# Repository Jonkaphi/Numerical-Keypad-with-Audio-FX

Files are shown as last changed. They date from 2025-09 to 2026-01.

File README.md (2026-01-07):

# Mechanical Numerical Keypad with local Audio FX
The desire to make this little keypad came from idea to reuse a some of the parts from a broken keyboard someone gave me.

The extra little feature of having audio fx being played locally on the keyboard with each button press, was from one of the commenters on reddit related to a post. The sound files will be read from the placed SD card. Currently the audio that can be played is from 8 to 16 kHz kHz sample rate with 16 bit signed PCM.

The lower level sd card interface for the file system used in the project was made by Khaled Magdy in their post on DeepBlueMbedded

### Top View
kuk35721-1920

### Bottom View



## Issues as of 08/2025
* Current USB port part is not vertically offset, which collides with the PCB, read "Connectors" page in the schematic.
* Encoder for PC system audio still glitches at times, but its significantly better compared to previous build versions
* Audio streaming and polling of the key inputs is done on a single thread, resulting in less than satisfactory responsiveness

## Future work
* Move to a MCU series that include SDIO for the SD card, has more flash to as to implement some sort of RTOS, and or has a second core to handle the audio streaming.
* General rework of the PCB, redesign of the audio front-end to have better amplification of the DAC data stream.

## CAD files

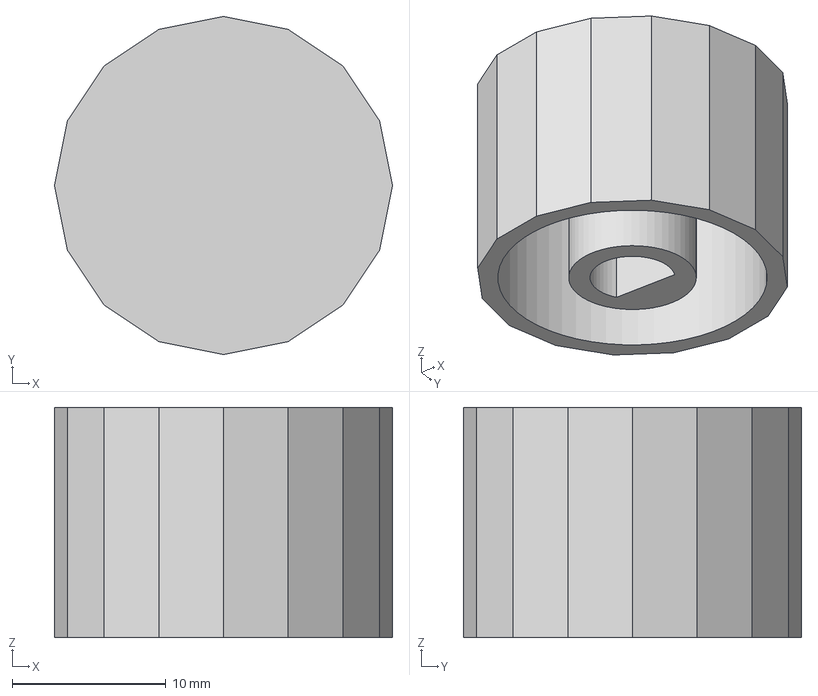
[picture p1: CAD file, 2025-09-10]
Hardware/keyboard_case_wip/volume knob v17.step
22.0 x 22.0 x 15.0 mm

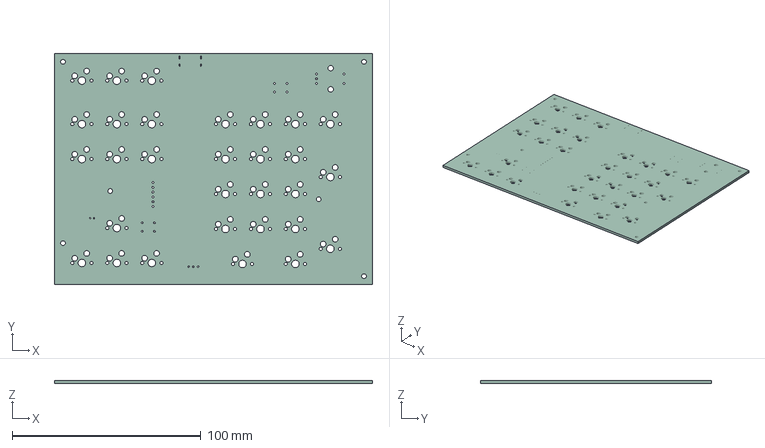
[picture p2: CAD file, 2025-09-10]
Hardware/kicad project/Body1.3mf
168.3 x 122.5 x 1.60 mm

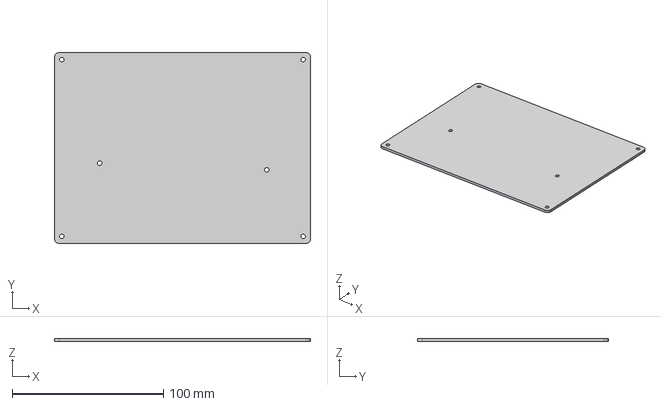
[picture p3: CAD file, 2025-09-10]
Hardware/keyboard_case_wip/bottom_plate v24.step
169.0 x 126.0 x 2.00 mm

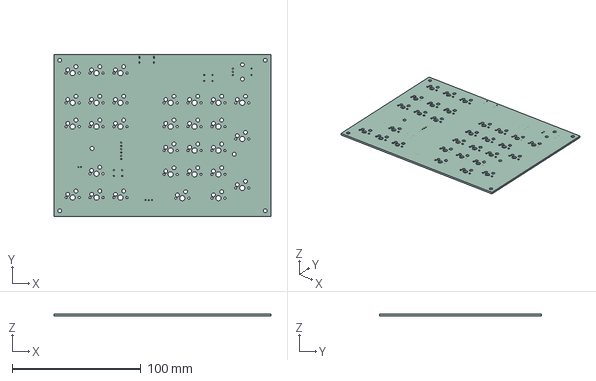
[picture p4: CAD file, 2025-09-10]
Hardware/kicad project/Keyboard_stm32.step
168.3 x 125.7 x 1.60 mm

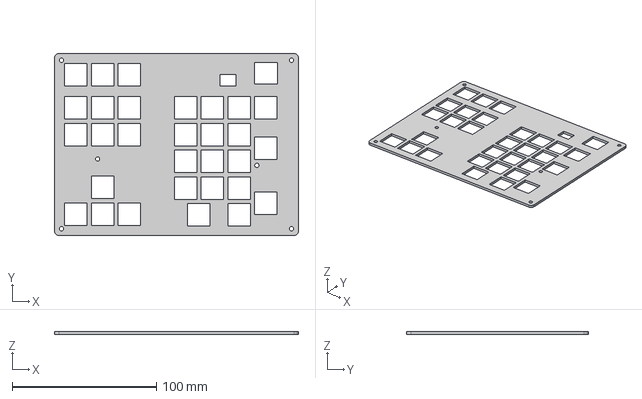
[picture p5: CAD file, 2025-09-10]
Hardware/keyboard_case_wip/top_plate v22.step
169.0 x 126.0 x 2.00 mm

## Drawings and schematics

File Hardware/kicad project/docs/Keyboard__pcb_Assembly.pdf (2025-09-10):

NRST | Power
SWDIO C²⁹ | FB3 R7

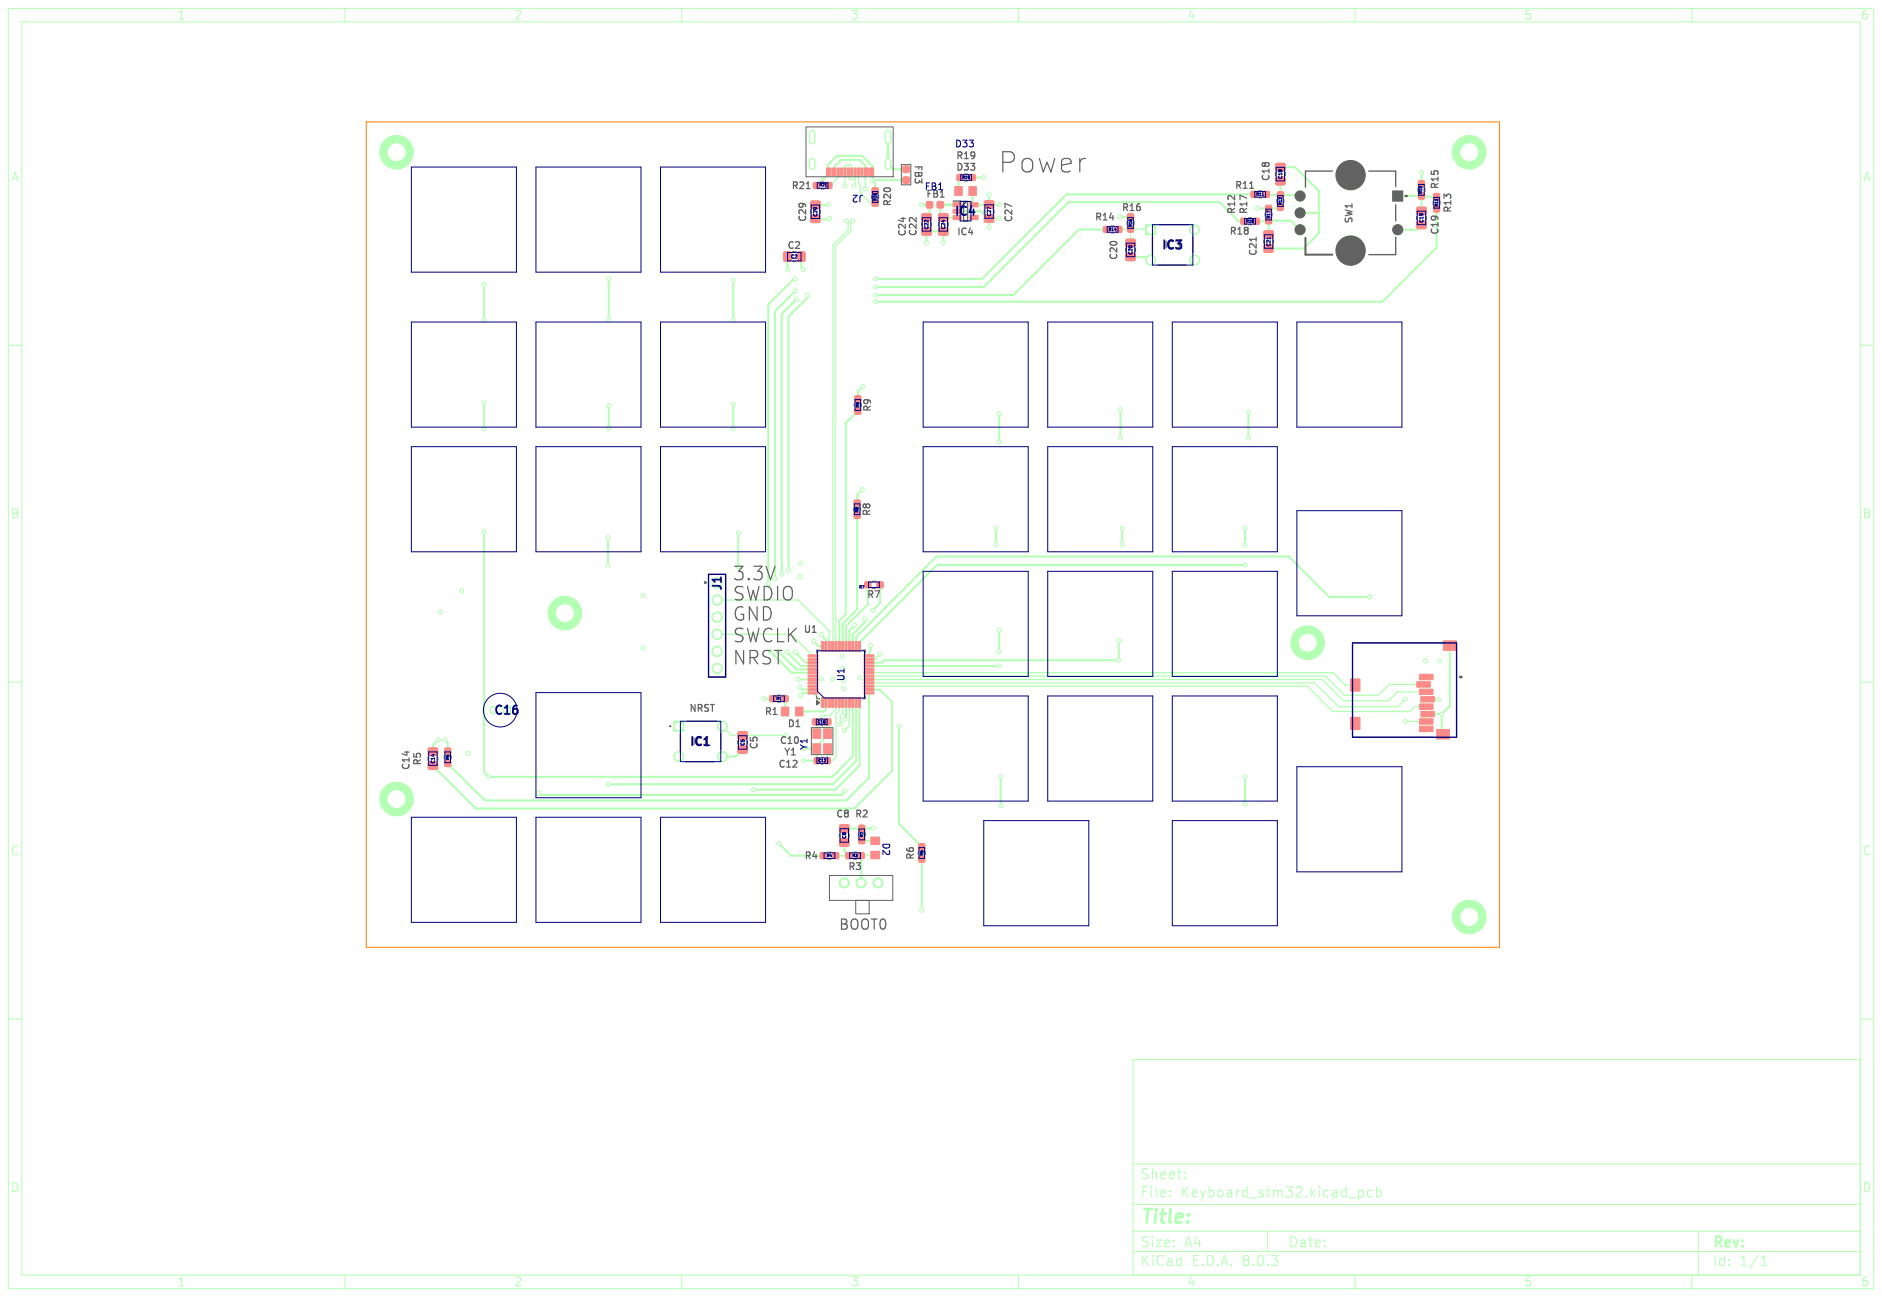
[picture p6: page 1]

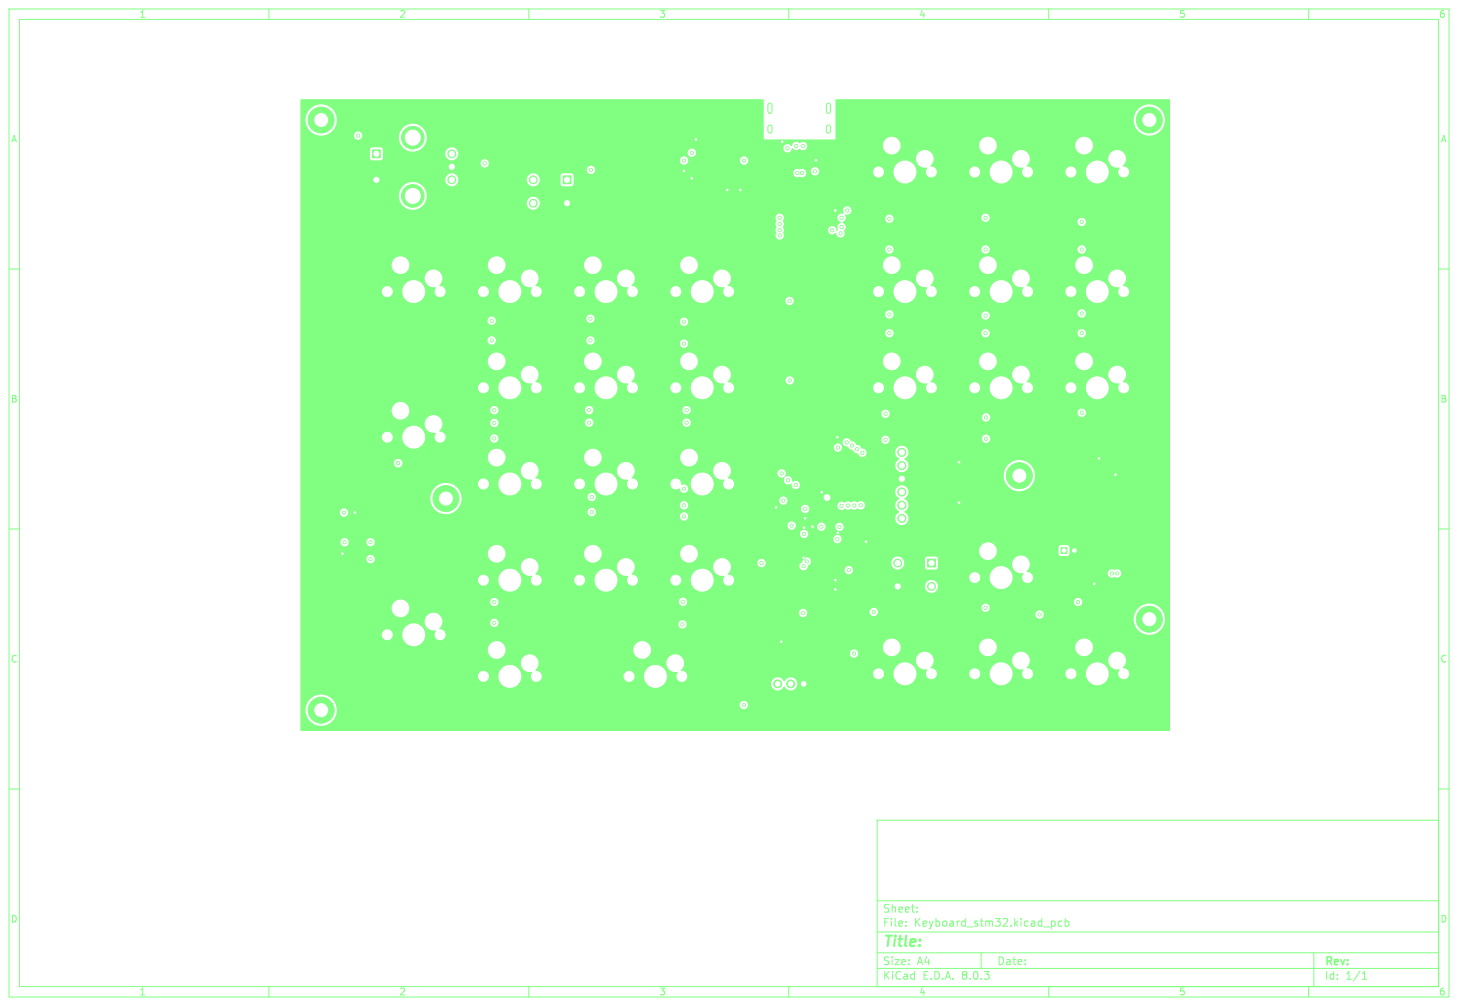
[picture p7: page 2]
D Date: KiCad; E.D.A. 8.0.3 Size: A4; Rev:

Id: 1/1 Title: File: Keyboard_stm32.kicad_pcb Sheet:

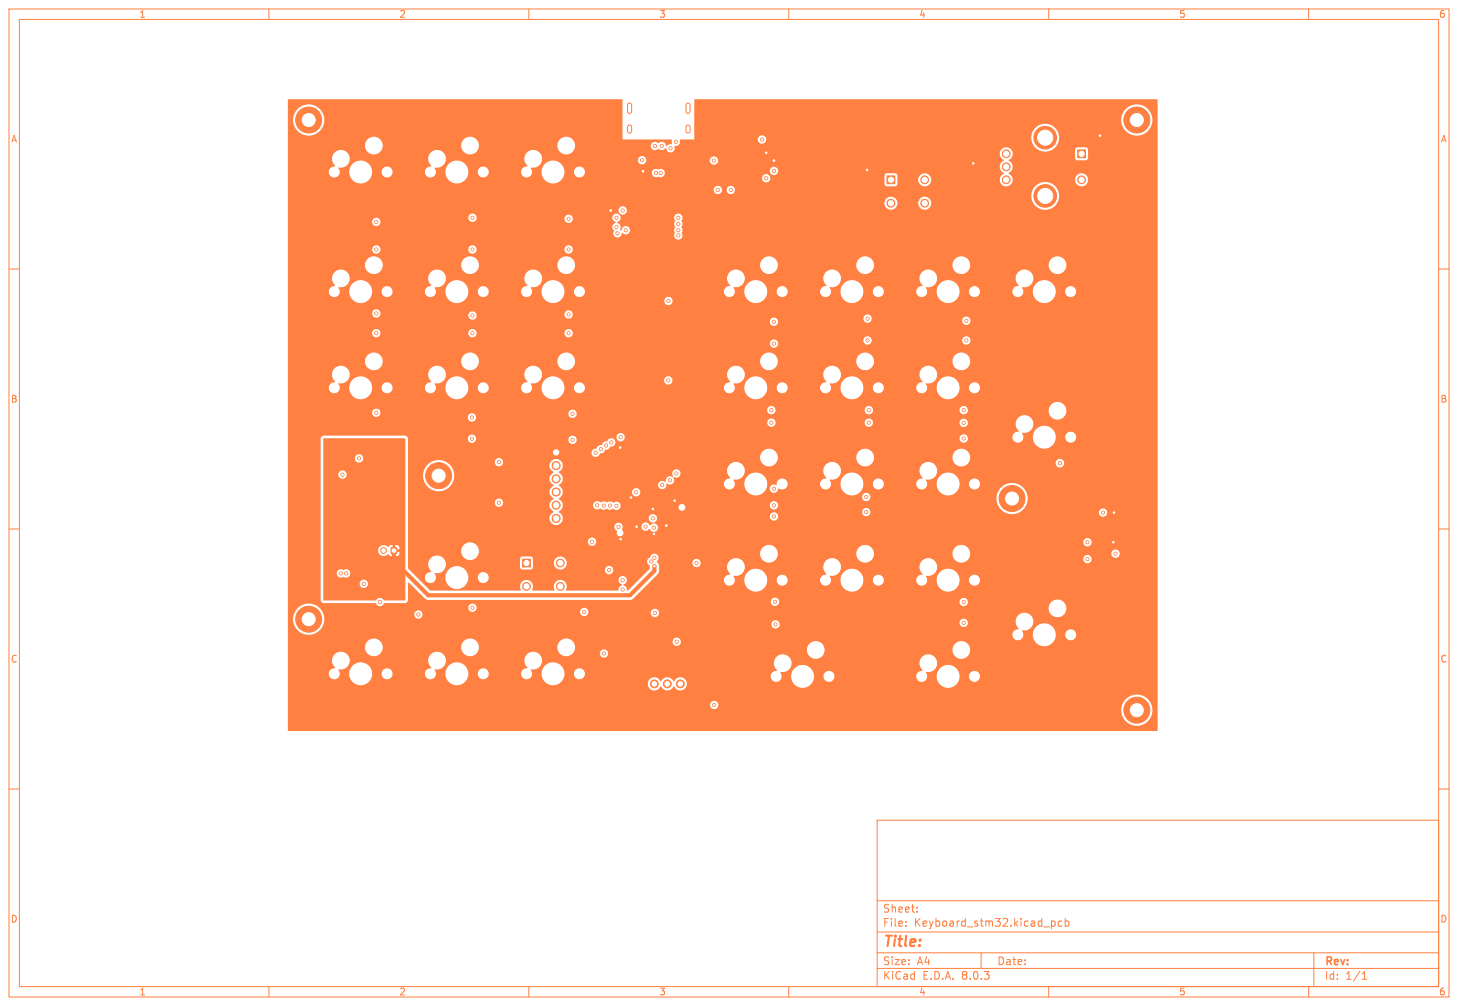
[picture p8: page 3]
D Date: KiCad; E.D.A. 8.0.3 Size: A4; Rev:

Id: 1/1 Title: File: Keyboard_stm32.kicad_pcb Sheet:

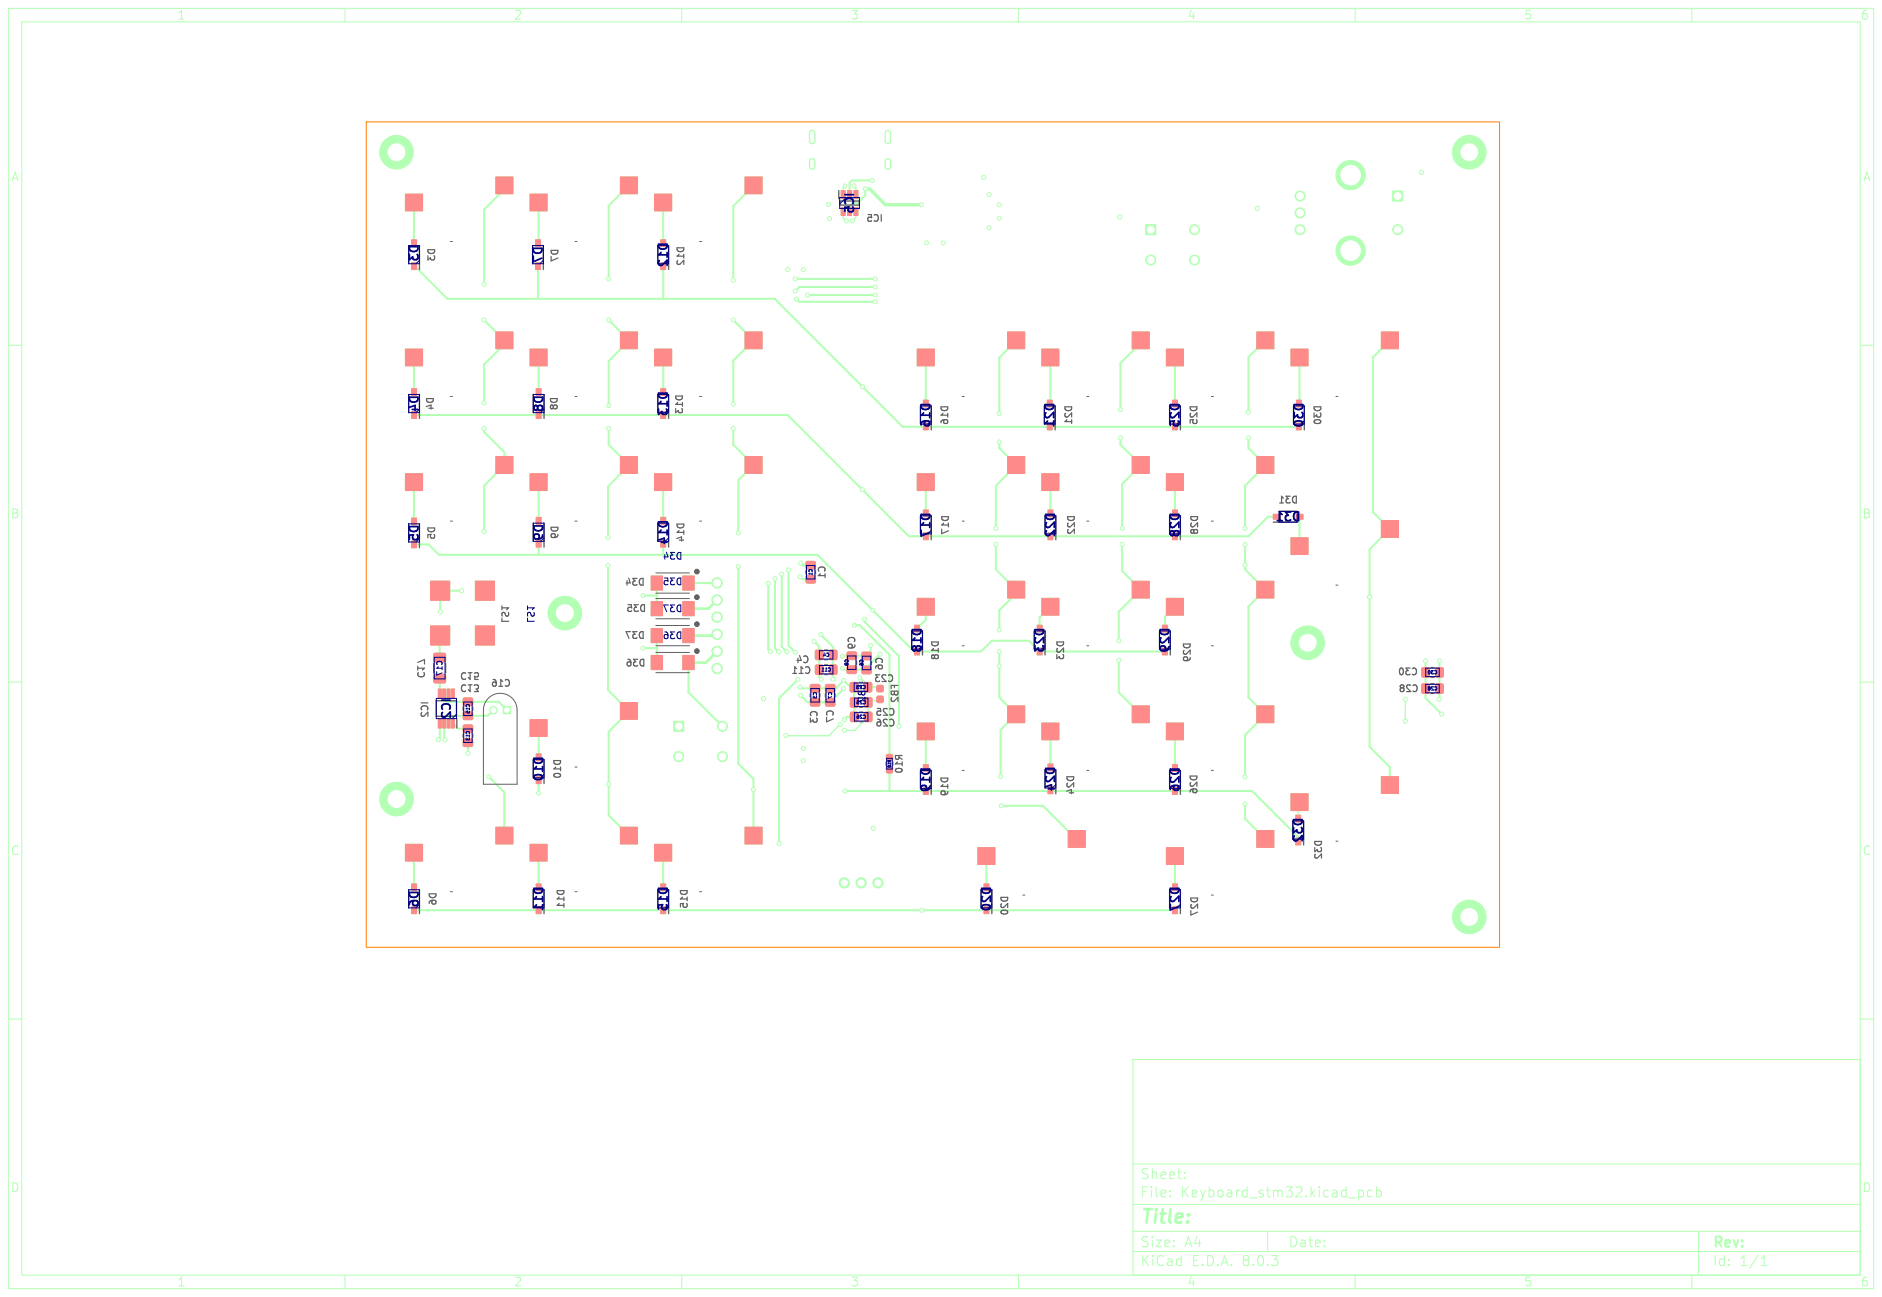
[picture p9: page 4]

Id: 1/1 Title: File: Keyboard_stm32.kicad_pcb Sheet:

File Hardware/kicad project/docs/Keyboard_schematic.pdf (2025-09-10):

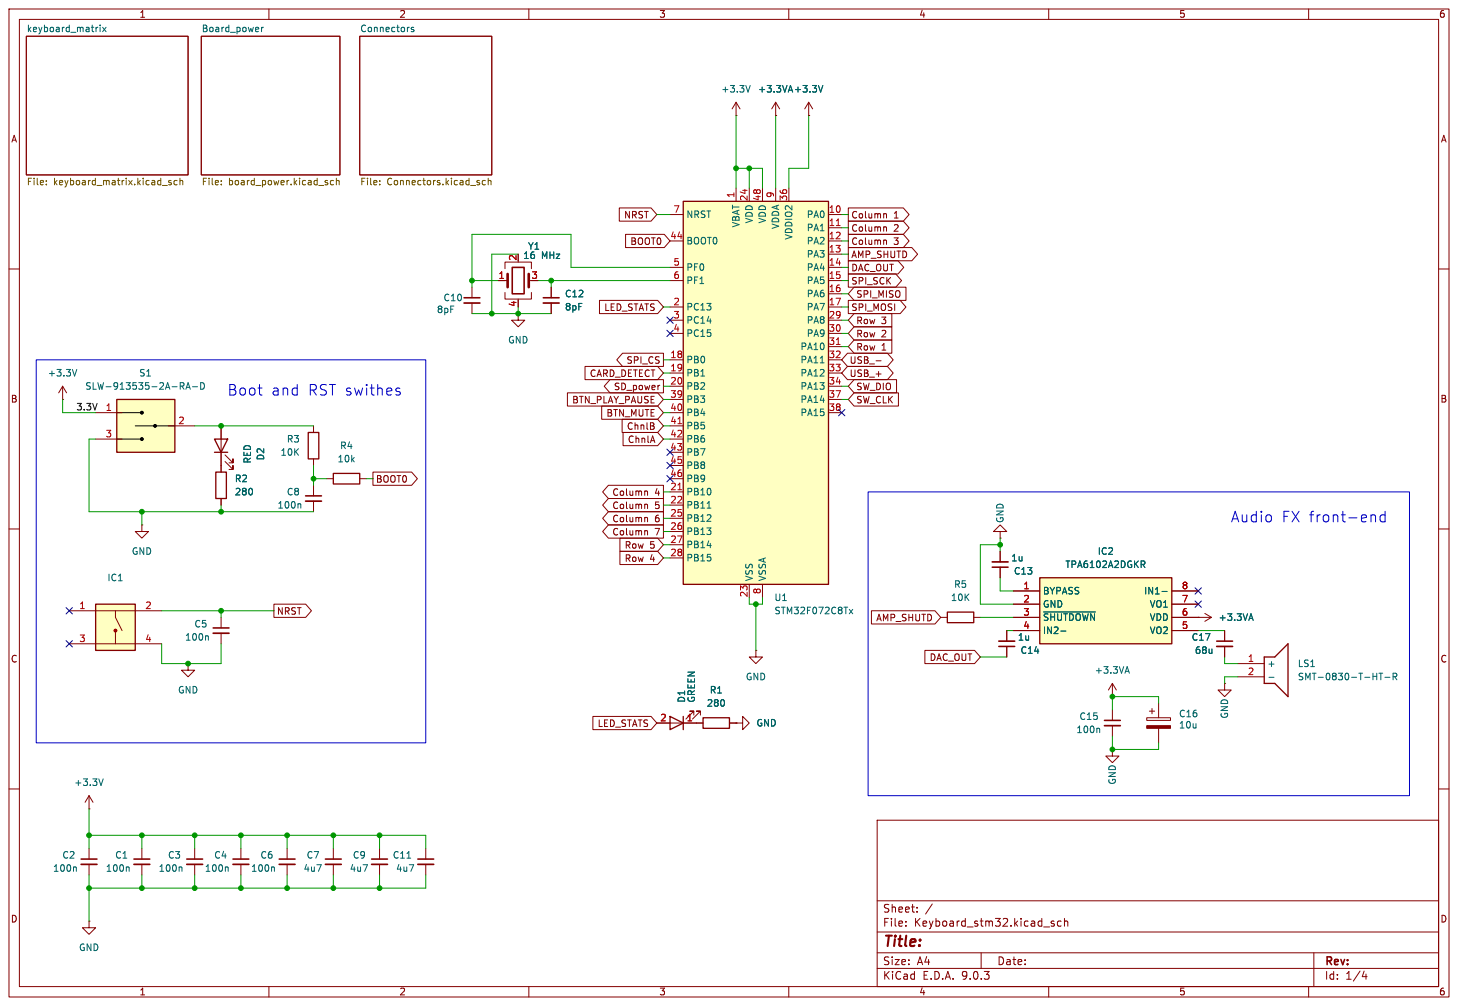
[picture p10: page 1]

1 VDD 24 VSS 23 VDD 48 VSSA

Audio FX front-end

Id: 1/4 Title: File: Keyboard_stm32.kicad_sch Sheet: /

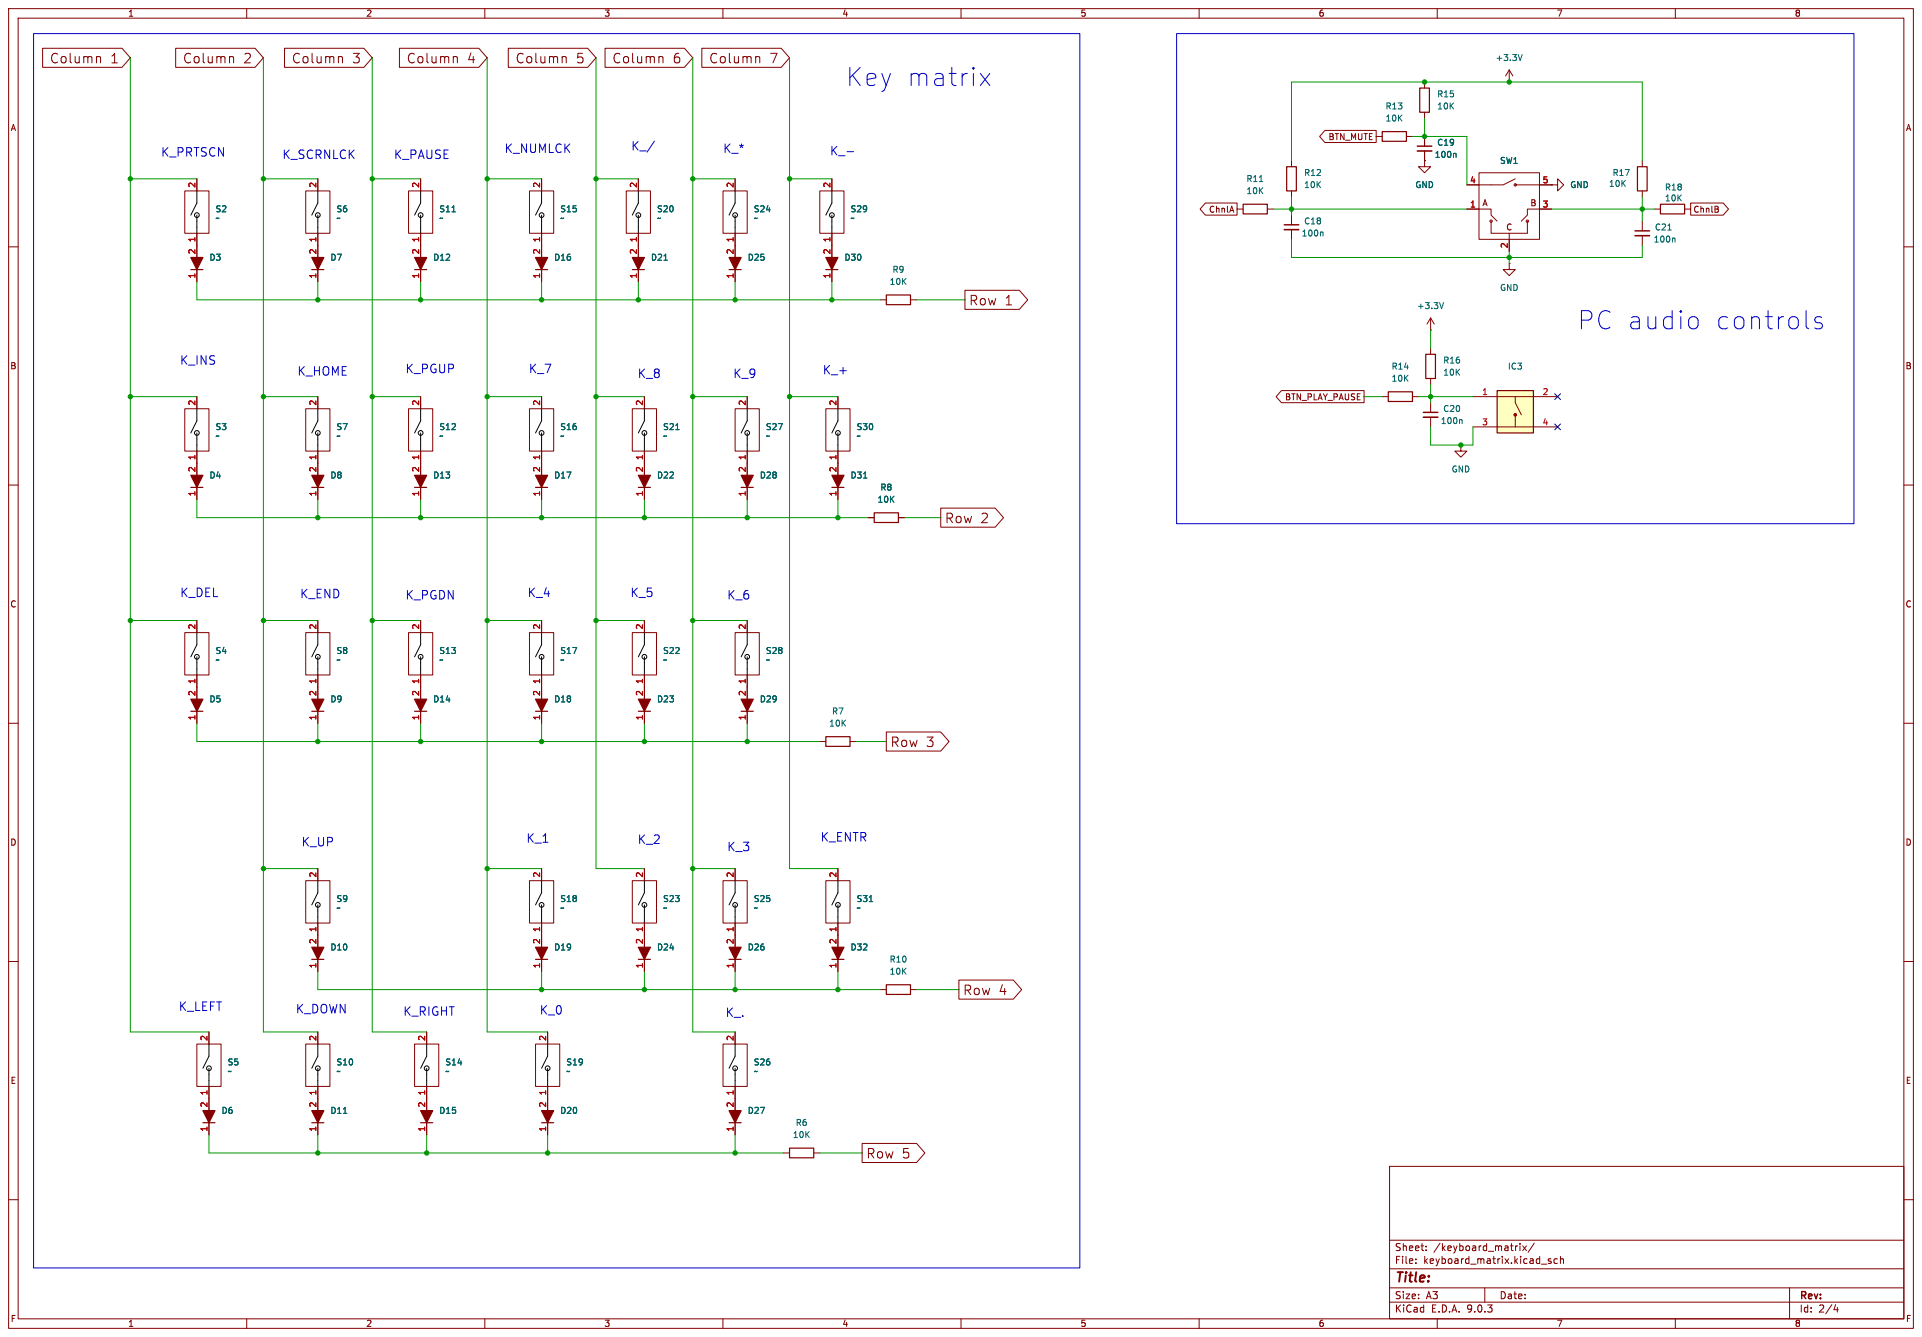
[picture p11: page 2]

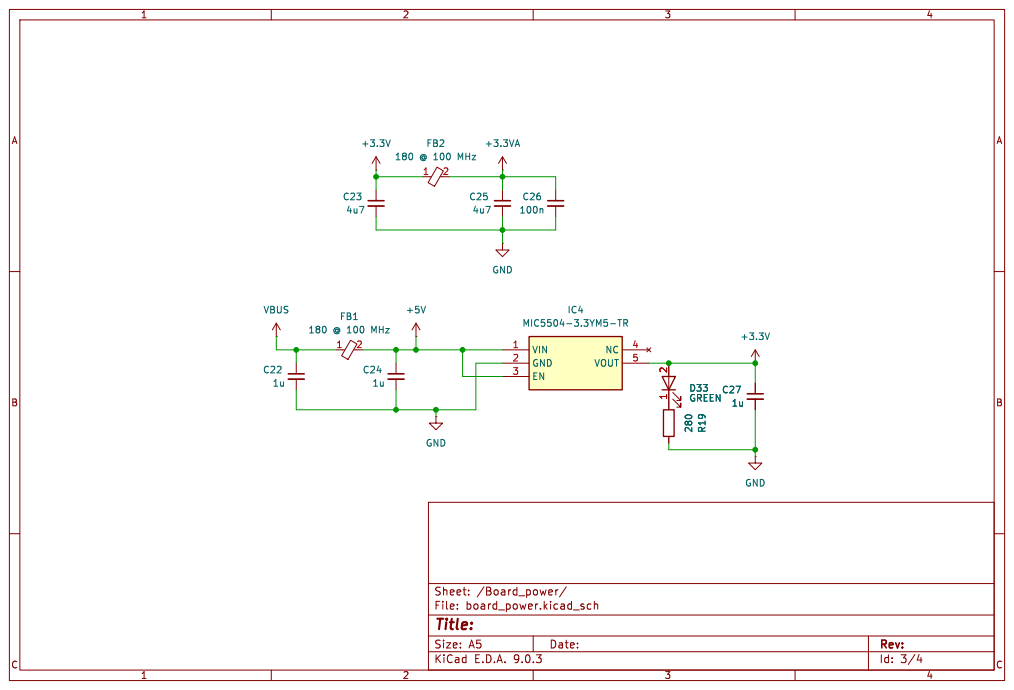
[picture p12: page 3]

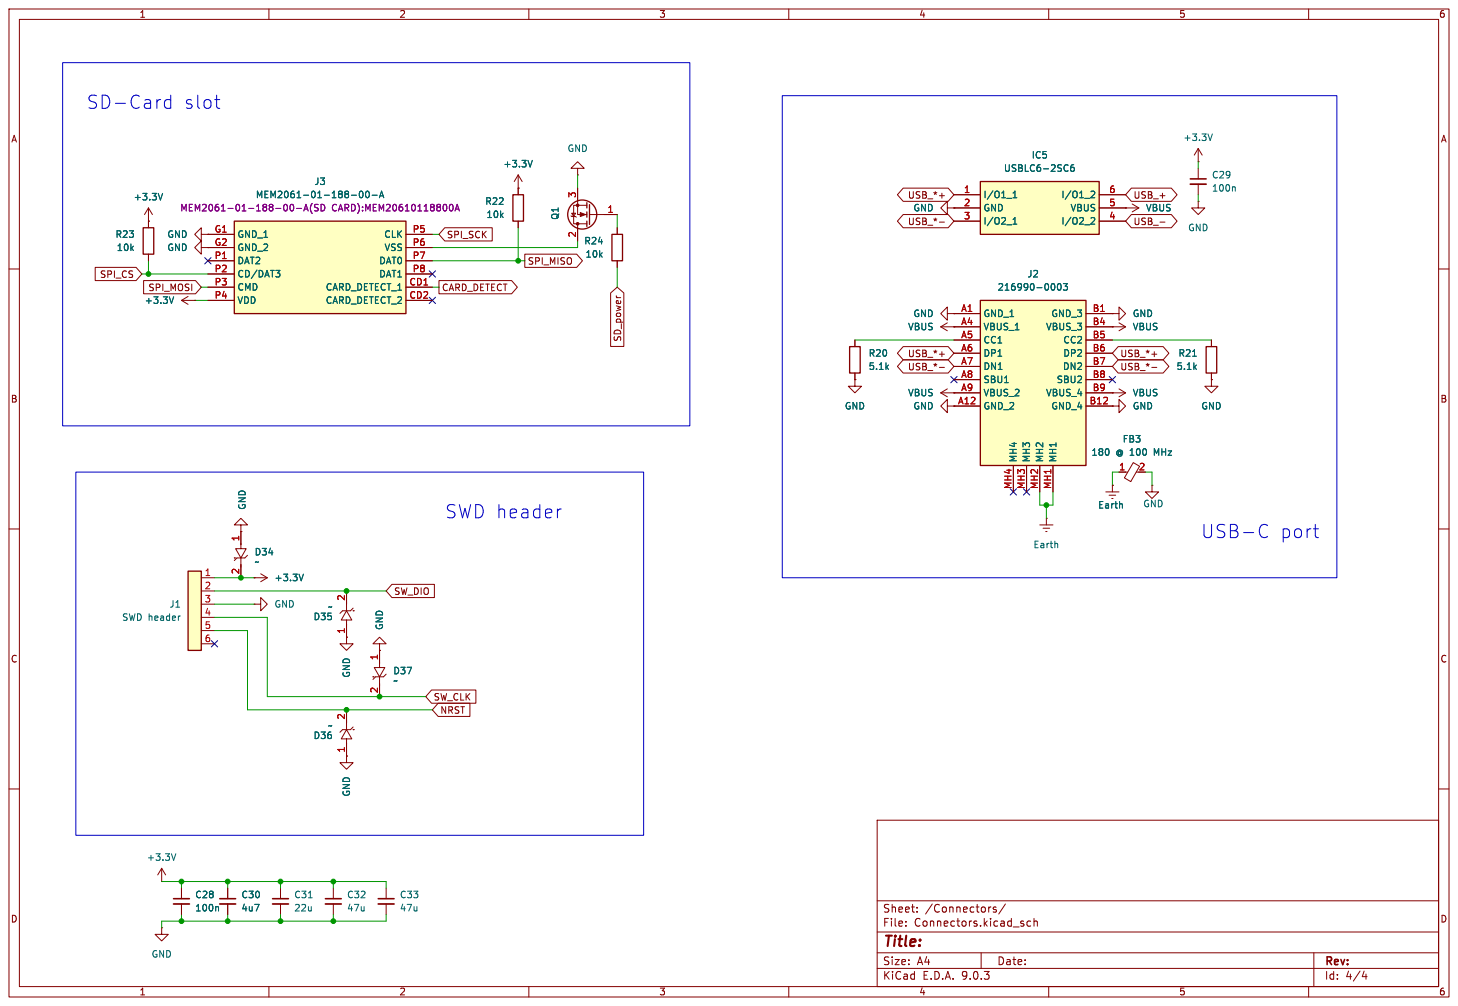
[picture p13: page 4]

Id: 4/4 Title: File: Connectors.kicad_sch Sheet: /Connectors/

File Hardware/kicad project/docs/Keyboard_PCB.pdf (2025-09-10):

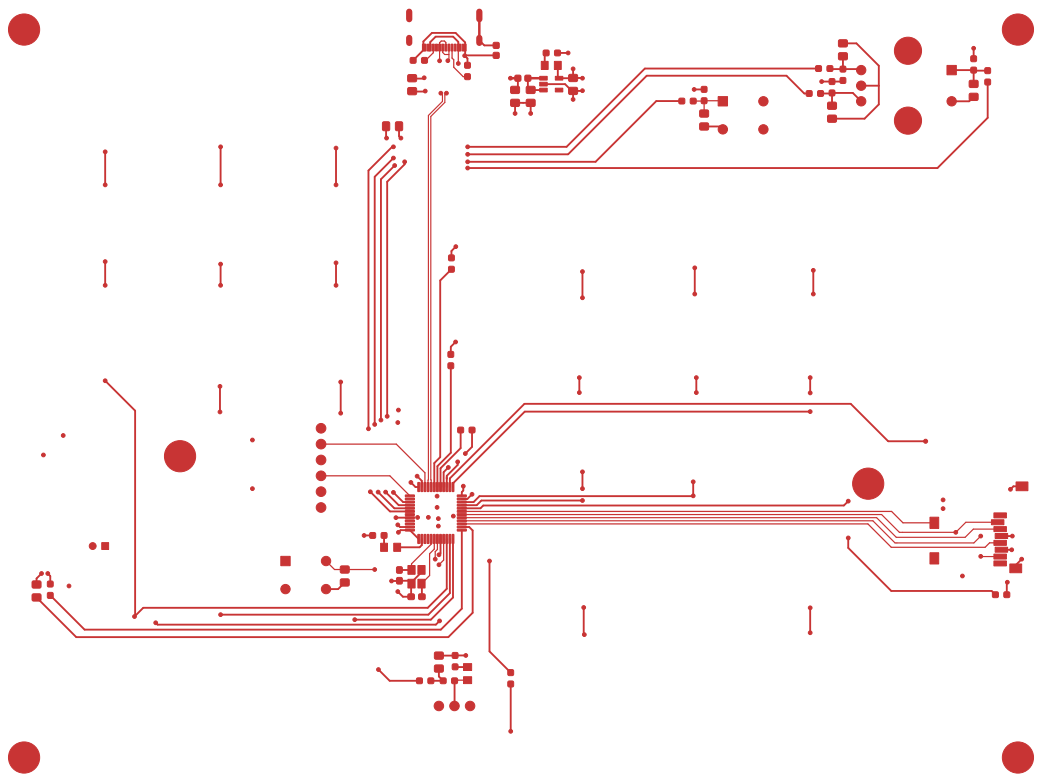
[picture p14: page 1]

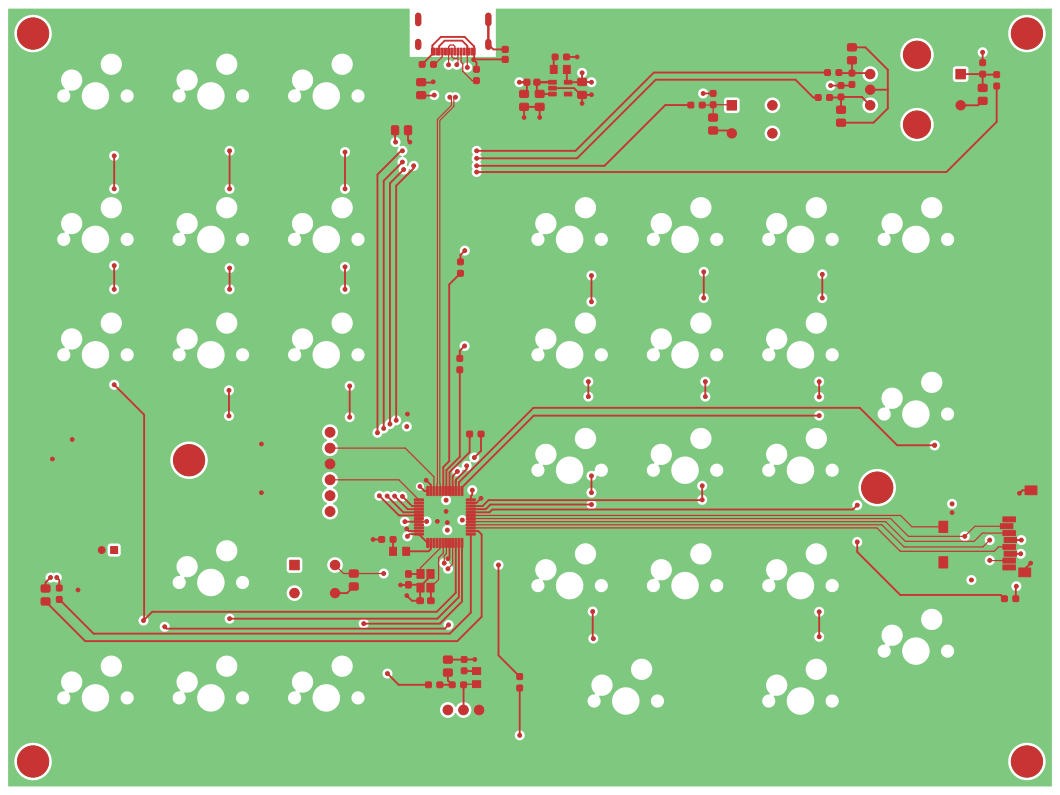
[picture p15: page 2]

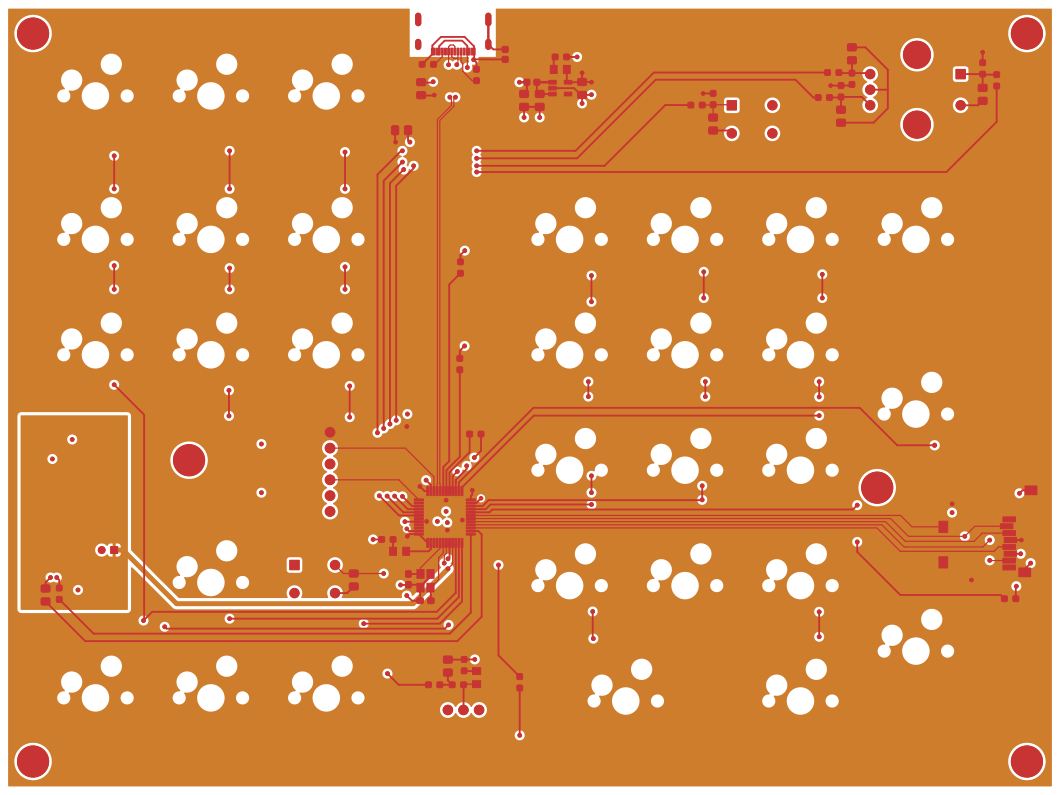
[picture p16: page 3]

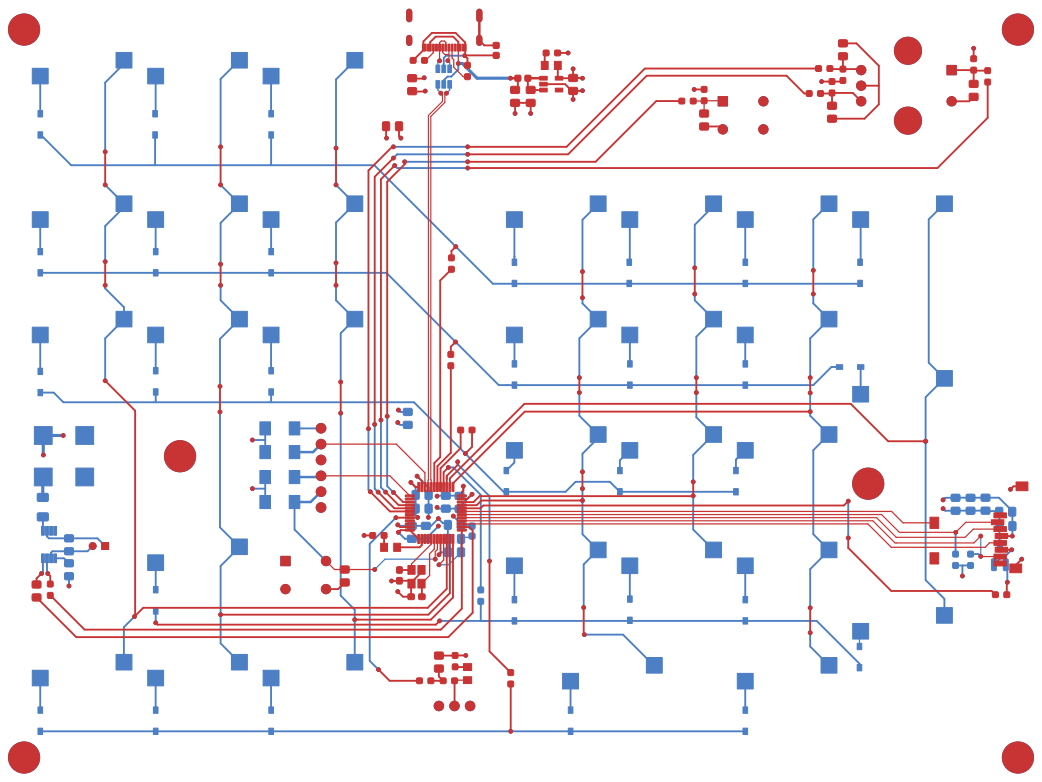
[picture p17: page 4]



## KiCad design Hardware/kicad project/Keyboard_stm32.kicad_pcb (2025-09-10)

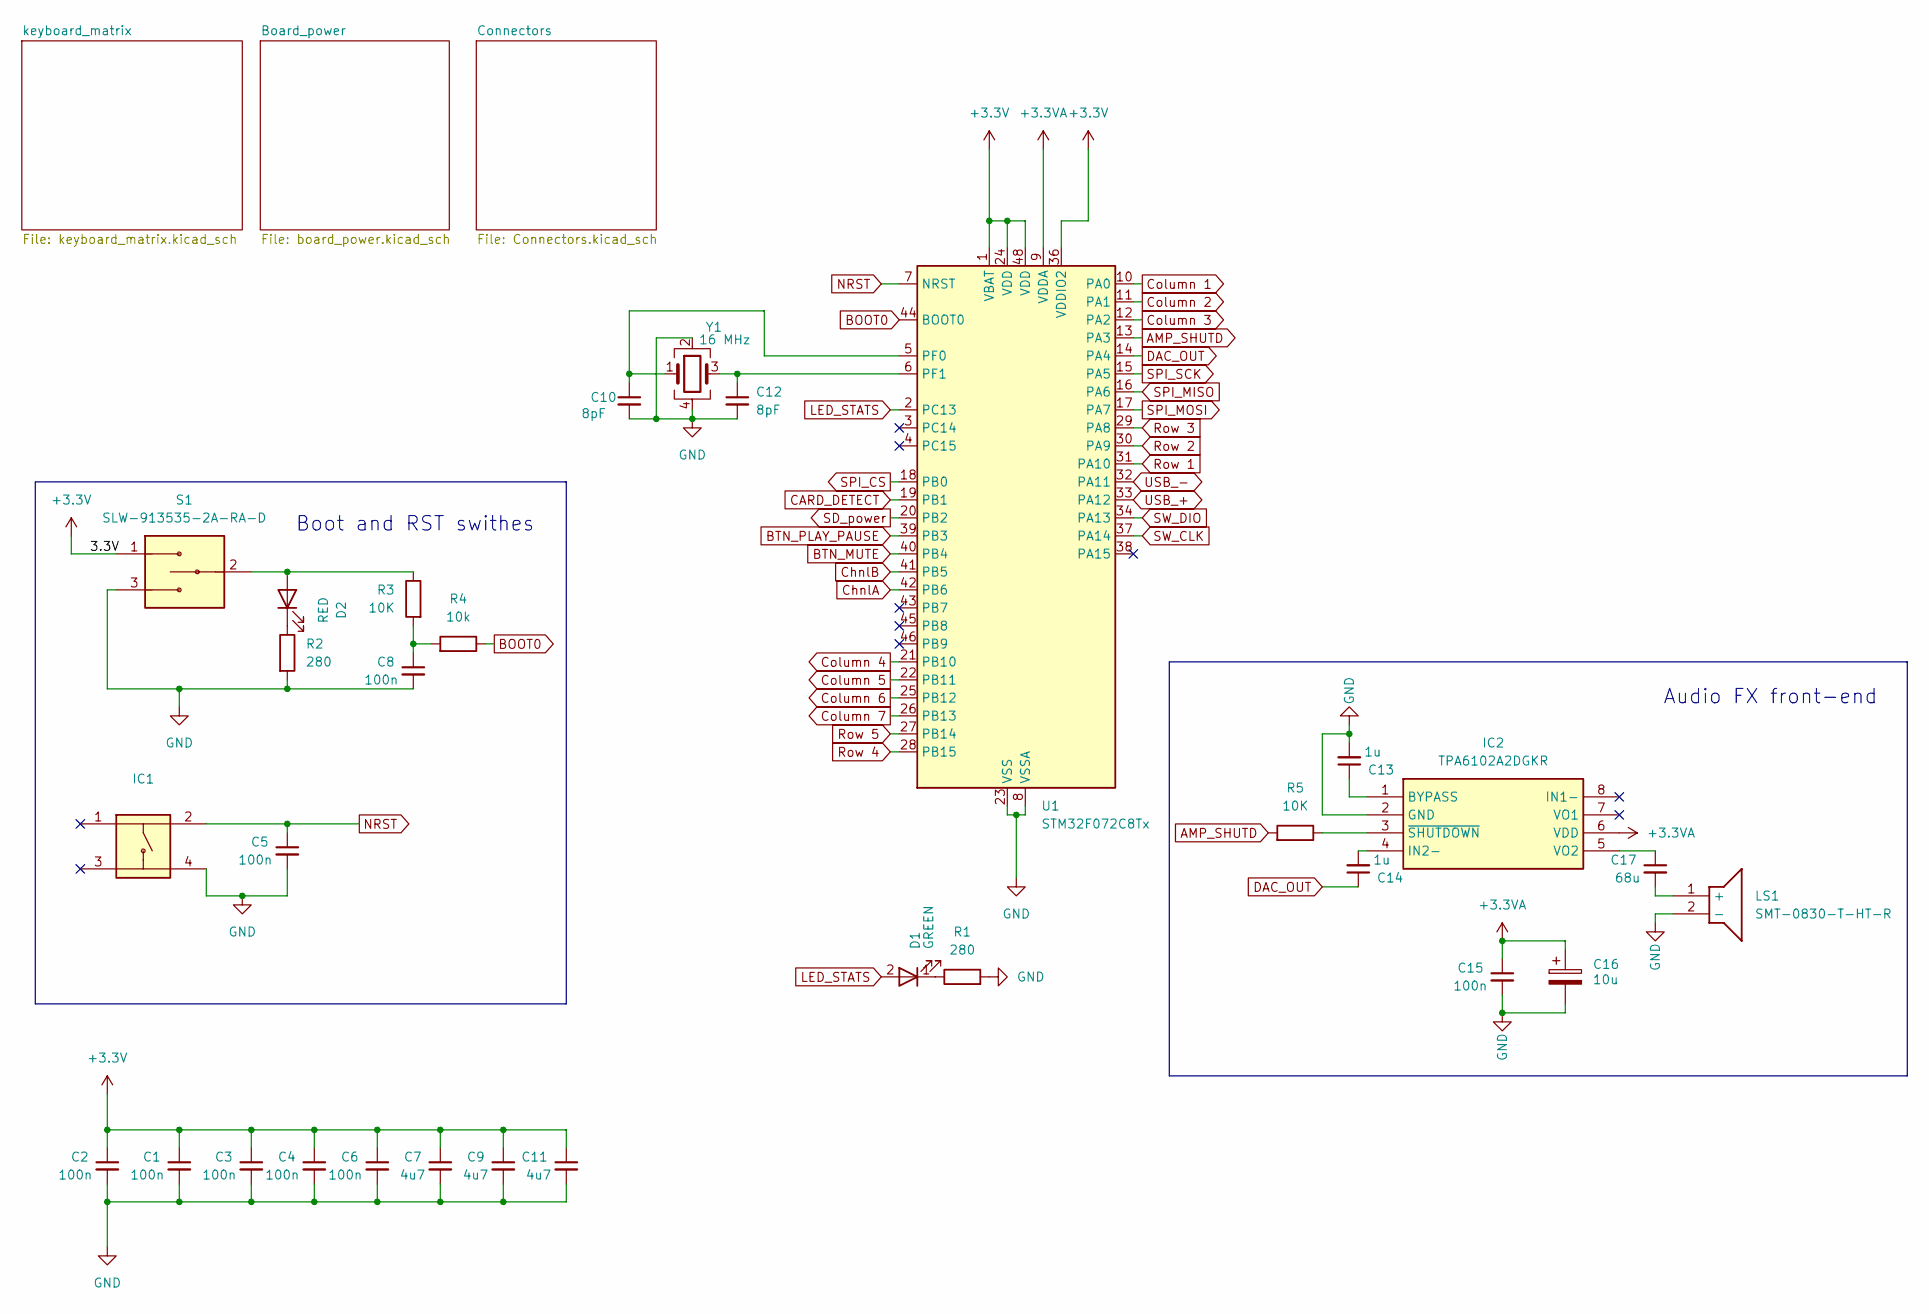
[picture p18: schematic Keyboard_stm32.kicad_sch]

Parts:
C1, C2, C3, C4, C5, C6, C8, C15: 100n; C_0805_2012Metric_Pad1.18x1.45mm_HandSolder
C7, C9, C11: 4u7; C_0805_2012Metric_Pad1.18x1.45mm_HandSolder
C10, C12: 8pF; C_0603_1608Metric_Pad1.08x0.95mm_HandSolder
C13, C14: 1u; C_0805_2012Metric_Pad1.18x1.45mm_HandSolder
C16: 10u; CAPPRD200W52D500H1250
C17: 68u; C_1206_3216Metric_Pad1.33x1.80mm_HandSolder
D1: GREEN; 150080VS75000
D2: RED; 150080VS75000
IC1: TS02-66-80-BK-160-LCR-D; TS026680BK160LCRD; Manufacturer_Part_Number TS02-66-80-BK-160-LCR-D; Mouser Part Number 179-TS026680BK160LCR
IC2: TPA6102A2DGKR; SOP65P490X110-8N; Manufacturer_Part_Number TPA6102A2DGKR; Mouser Part Number 595-TPA6102A2DGKR
LS1: SMT-0830-T-HT-R; Manufacturer_Part_Number TE122001-6; Mouser Part Number 497-TE122001-6
R1, R2: 280; R_0603_1608Metric_Pad0.98x0.95mm_HandSolder
R3, R5: 10K; R_0603_1608Metric_Pad0.98x0.95mm_HandSolder
R4: 10k; R_0603_1608Metric_Pad0.98x0.95mm_HandSolder
S1: SLW-913535-2A-RA-D; Manufacturer_Part_Number EG1218; Mouser Part Number 612-EG1218
U1: STM32F072C8Tx; LQFP-48_7x7mm_P0.5mm
Y1: 16 MHz; TSX-3225_16.0000MF09Z-AC3

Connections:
AMP_SHUTD: R5.2, U1.13 (PA3)
BOOT0: R4.1, U1.44 (BOOT0)
BTN_MUTE: U1.40 (PB4); also elsewhere on the board
BTN_PLAY_PAUSE: U1.39 (PB3); also elsewhere on the board
CARD_DETECT: U1.19 (PB1); also elsewhere on the board
ChnlA: U1.42 (PB6); also elsewhere on the board
ChnlB: U1.41 (PB5); also elsewhere on the board
Column 1: U1.10 (PA0); also elsewhere on the board
Column 2: U1.11 (PA1); also elsewhere on the board
Column 3: U1.12 (PA2); also elsewhere on the board
Column 4: U1.21 (PB10); also elsewhere on the board
Column 5: U1.22 (PB11); also elsewhere on the board
Column 6: U1.25 (PB12); also elsewhere on the board
Column 7: U1.26 (PB13); also elsewhere on the board
DAC_OUT: C14.1, U1.14 (PA4)
LED_STATS: D1.2, U1.2 (PC13)
NRST: C5.1, IC1.2, U1.7 (NRST); also elsewhere on the board
unnamed: C8.1, R3.2, R4.2
unnamed: D1.1, R1.1
unnamed: D2.2 (A), R3.1, S1.2
unnamed: D2.1 (K), R2.1
unnamed: C13.1, IC2.1 (BYPASS)
unnamed: C14.2, IC2.4 (IN2-)
unnamed: C17.1, IC2.5 (VO2)
unnamed: IC2.3 (~SHUTDOWN), R5.1
unnamed: C17.2, LS1.1 (+)
unnamed: C10.1, U1.5 (PF0), Y1.1
unnamed: C12.1, U1.6 (PF1), Y1.3
Row 1: U1.31 (PA10); also elsewhere on the board
Row 2: U1.30 (PA9); also elsewhere on the board
Row 3: U1.29 (PA8); also elsewhere on the board
Row 4: U1.28 (PB15); also elsewhere on the board
Row 5: U1.27 (PB14); also elsewhere on the board
SD_power: U1.20 (PB2); also elsewhere on the board
SPI_CS: U1.18 (PB0); also elsewhere on the board
SPI_MISO: U1.16 (PA6); also elsewhere on the board
SPI_MOSI: U1.17 (PA7); also elsewhere on the board
SPI_SCK: U1.15 (PA5); also elsewhere on the board
SW_CLK: U1.37 (PA14); also elsewhere on the board
SW_DIO: U1.34 (PA13); also elsewhere on the board
USB_+: U1.33 (PA12); also elsewhere on the board
USB_-: U1.32 (PA11); also elsewhere on the board

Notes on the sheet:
Boot and RST swithes
Audio FX front-end

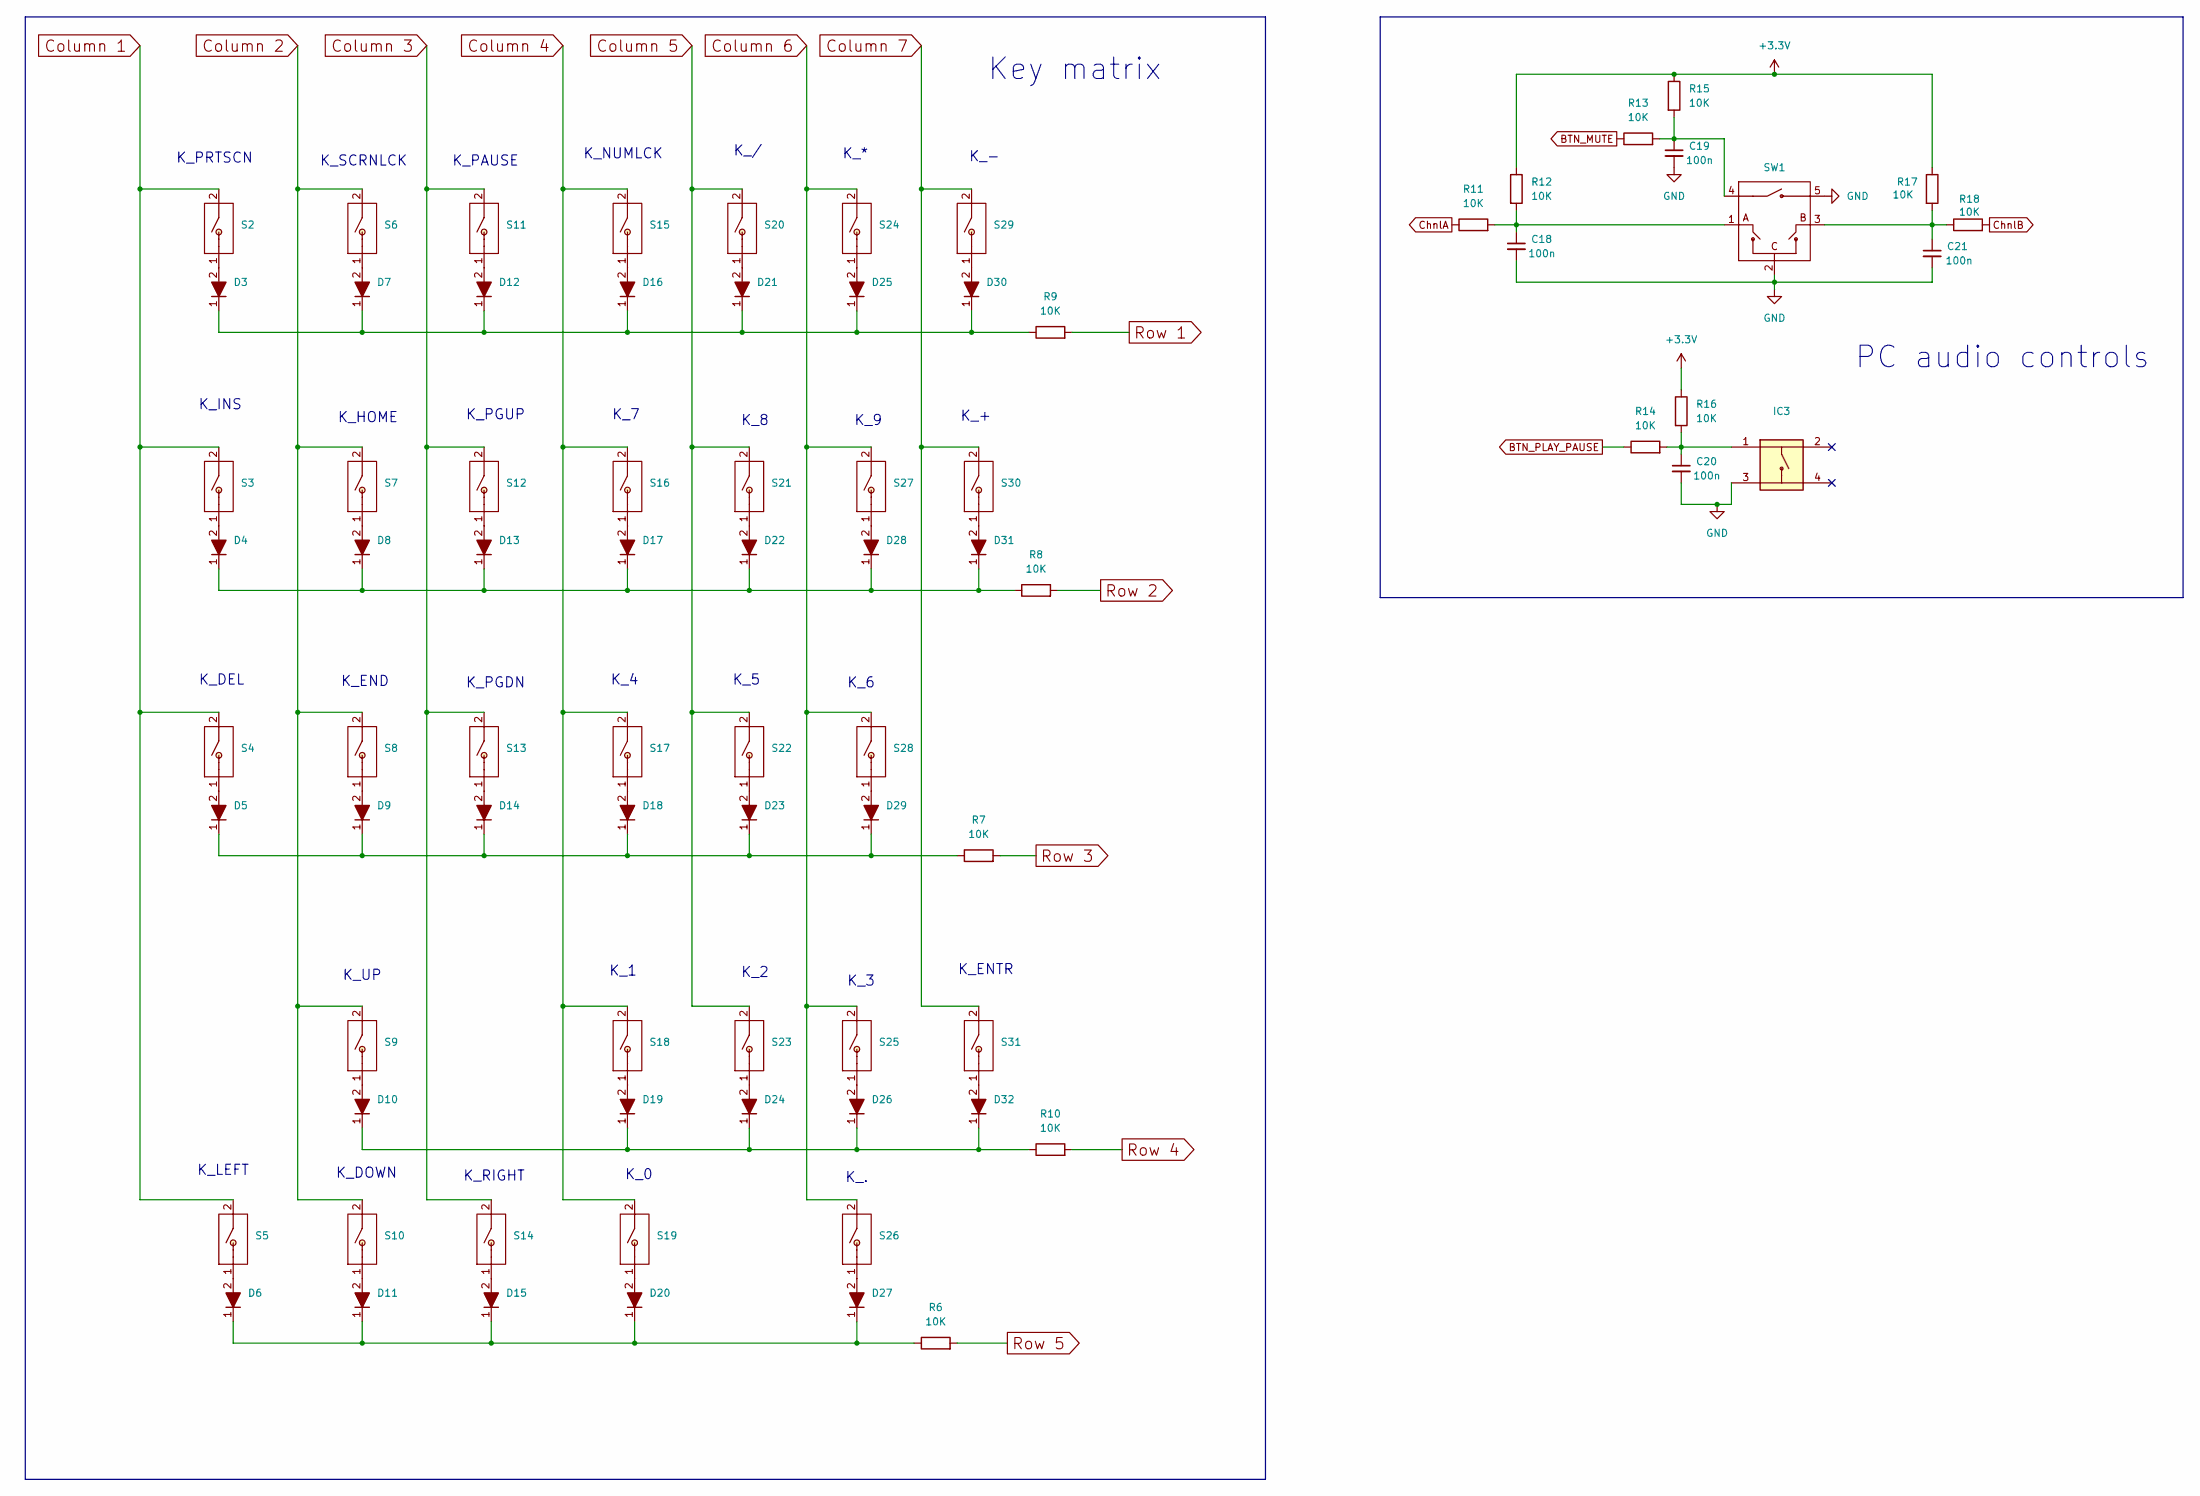
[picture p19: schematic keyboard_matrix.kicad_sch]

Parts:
C18, C19, C20, C21: 100n; C_0805_2012Metric_Pad1.18x1.45mm_HandSolder
D3, D4, D5, D6, D7, D8, D9, D10, D11, D12, D13, D14, D15, D16, D17, D18, D19, D20, D21, D22, D23, D24, D25, D26, D27, D28, D29, D30, D31, D32: 1N4148W; SODFL3816X120N; Manufacturer_Part_Number 1N4148W; Mouser Part Number 637-1N4148W
IC3: TS02-66-80-BK-160-LCR-D; TS026680BK160LCRD; Manufacturer_Part_Number TS02-66-80-BK-160-LCR-D; Mouser Part Number 179-TS026680BK160LCR
R6, R7, R8, R9, R10, R11, R12, R13, R14, R15, R16, R17, R18: 10K; R_0603_1608Metric_Pad0.98x0.95mm_HandSolder
S2, S3, S4, S5, S6, S7, S8, S9, S10, S11, S12, S13, S14, S15, S16, S17, S18, S19, S20, S21, S22, S23, S24, S25, S26, S27, S28, S29, S30, S31: Cherry-MX_PCB-Mounted_LTST-A683CEGBW_Kailh_Socket
SW1: PEC12R-4125F-S0012; PEC12R4125FS0012; Manufacturer_Part_Number PEC12R-4125F-S0012; Mouser Part Number 652-PEC12R-4125F-S12

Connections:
BTN_MUTE: R13.1; also elsewhere on the board
BTN_PLAY_PAUSE: R14.1; also elsewhere on the board
ChnlA: R11.1; also elsewhere on the board
ChnlB: R18.2; also elsewhere on the board
Column 1: S2.2, S3.2, S4.2, S5.2; also elsewhere on the board
Column 2: S6.2, S7.2, S8.2, S9.2, S10.2; also elsewhere on the board
Column 3: S11.2, S12.2, S13.2, S14.2; also elsewhere on the board
Column 4: S15.2, S16.2, S17.2, S18.2, S19.2; also elsewhere on the board
Column 5: S20.2, S21.2, S22.2, S23.2; also elsewhere on the board
Column 6: S24.2, S25.2, S26.2, S27.2, S28.2; also elsewhere on the board
Column 7: S29.2, S30.2, S31.2; also elsewhere on the board
unnamed: C18.1, R11.2, R12.2, SW1.1
unnamed: C19.1, R13.2, R15.2, SW1.4
unnamed: C20.1, IC3.1, R14.2, R16.2
unnamed: C21.1, R17.2, R18.1, SW1.3
unnamed: D3.2 (A), S2.1
unnamed: D4.2 (A), S3.1
unnamed: D5.2 (A), S4.1
unnamed: D6.2 (A), S5.1
unnamed: D7.2 (A), S6.1
unnamed: D8.2 (A), S7.1
unnamed: D9.2 (A), S8.1
unnamed: D10.2 (A), S9.1
unnamed: D10.1 (K), D19.1 (K), D24.1 (K), D26.1 (K), D32.1 (K), R10.1
unnamed: D11.2 (A), S10.1
unnamed: D6.1 (K), D11.1 (K), D15.1 (K), D20.1 (K), D27.1 (K), R6.1
unnamed: D12.2 (A), S11.1
unnamed: D3.1 (K), D7.1 (K), D12.1 (K), D16.1 (K), D21.1 (K), D25.1 (K), D30.1 (K), R9.1
unnamed: D13.2 (A), S12.1
unnamed: D4.1 (K), D8.1 (K), D13.1 (K), D17.1 (K), D22.1 (K), D28.1 (K), D31.1 (K), R8.1
unnamed: D14.2 (A), S13.1
unnamed: D5.1 (K), D9.1 (K), D14.1 (K), D18.1 (K), D23.1 (K), D29.1 (K), R7.1
unnamed: D15.2 (A), S14.1
unnamed: D16.2 (A), S15.1
unnamed: D17.2 (A), S16.1
unnamed: D18.2 (A), S17.1
unnamed: D19.2 (A), S18.1
unnamed: D20.2 (A), S19.1
unnamed: D21.2 (A), S20.1
unnamed: D22.2 (A), S21.1
unnamed: D23.2 (A), S22.1
unnamed: D24.2 (A), S23.1
unnamed: D25.2 (A), S24.1
unnamed: D26.2 (A), S25.1
unnamed: D27.2 (A), S26.1
unnamed: D28.2 (A), S27.1
unnamed: D29.2 (A), S28.1
unnamed: D30.2 (A), S29.1
unnamed: D31.2 (A), S30.1
unnamed: D32.2 (A), S31.1
Row 1: R9.2; also elsewhere on the board
Row 2: R8.2; also elsewhere on the board
Row 3: R7.2; also elsewhere on the board
Row 4: R10.2; also elsewhere on the board
Row 5: R6.2; also elsewhere on the board

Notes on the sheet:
K_NUMLCK
K_END
K_.
K_7
K_UP
PC audio controls
K_ENTR
K_-
K_1
K_4
K_DEL
K_HOME
K_0
K_INS
K_PAUSE
K_9
Key matrix
K_LEFT
K_RIGHT
K_*
K_6
K_8
K_SCRNLCK
K_2
K_PGDN
K_/
K_PGUP
K_PRTSCN
K_3
K_DOWN
K_+
K_5

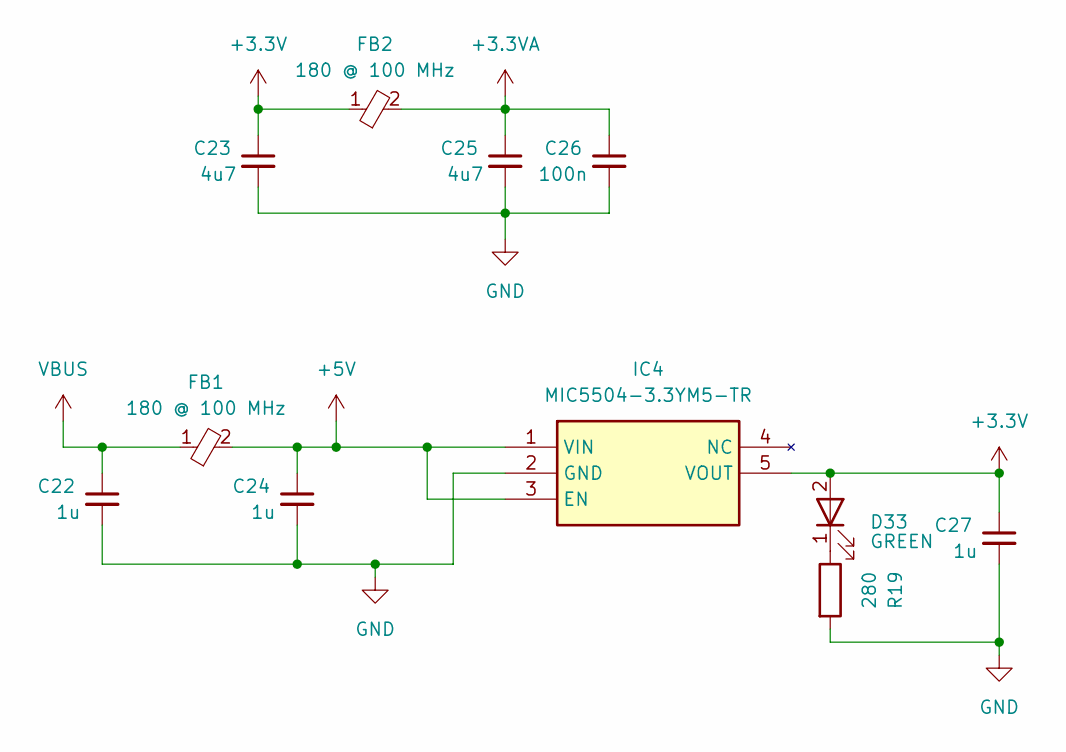
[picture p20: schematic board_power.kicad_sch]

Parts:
C22, C24, C27: 1u; C_0805_2012Metric_Pad1.18x1.45mm_HandSolder
C23, C25: 4u7; C_0805_2012Metric_Pad1.18x1.45mm_HandSolder
C26: 100n; C_0805_2012Metric_Pad1.18x1.45mm_HandSolder
D33: GREEN; 150080VS75000
FB1, FB2: 180 @ 100 MHz; ILBB0603ER181V
IC4: MIC5504-3.3YM5-TR; SOT95P280X145-5N; Manufacturer_Part_Number MIC5504-3.3YM5-TR; Mouser Part Number 998-MIC5504-3.3YM5TR
R19: 280; R_0603_1608Metric_Pad0.98x0.95mm_HandSolder

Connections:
+5V: C24.1, FB1.2, IC4.1 (VIN), IC4.3 (EN)
unnamed: D33.1, R19.1
VBUS: C22.1, FB1.1; also elsewhere on the board

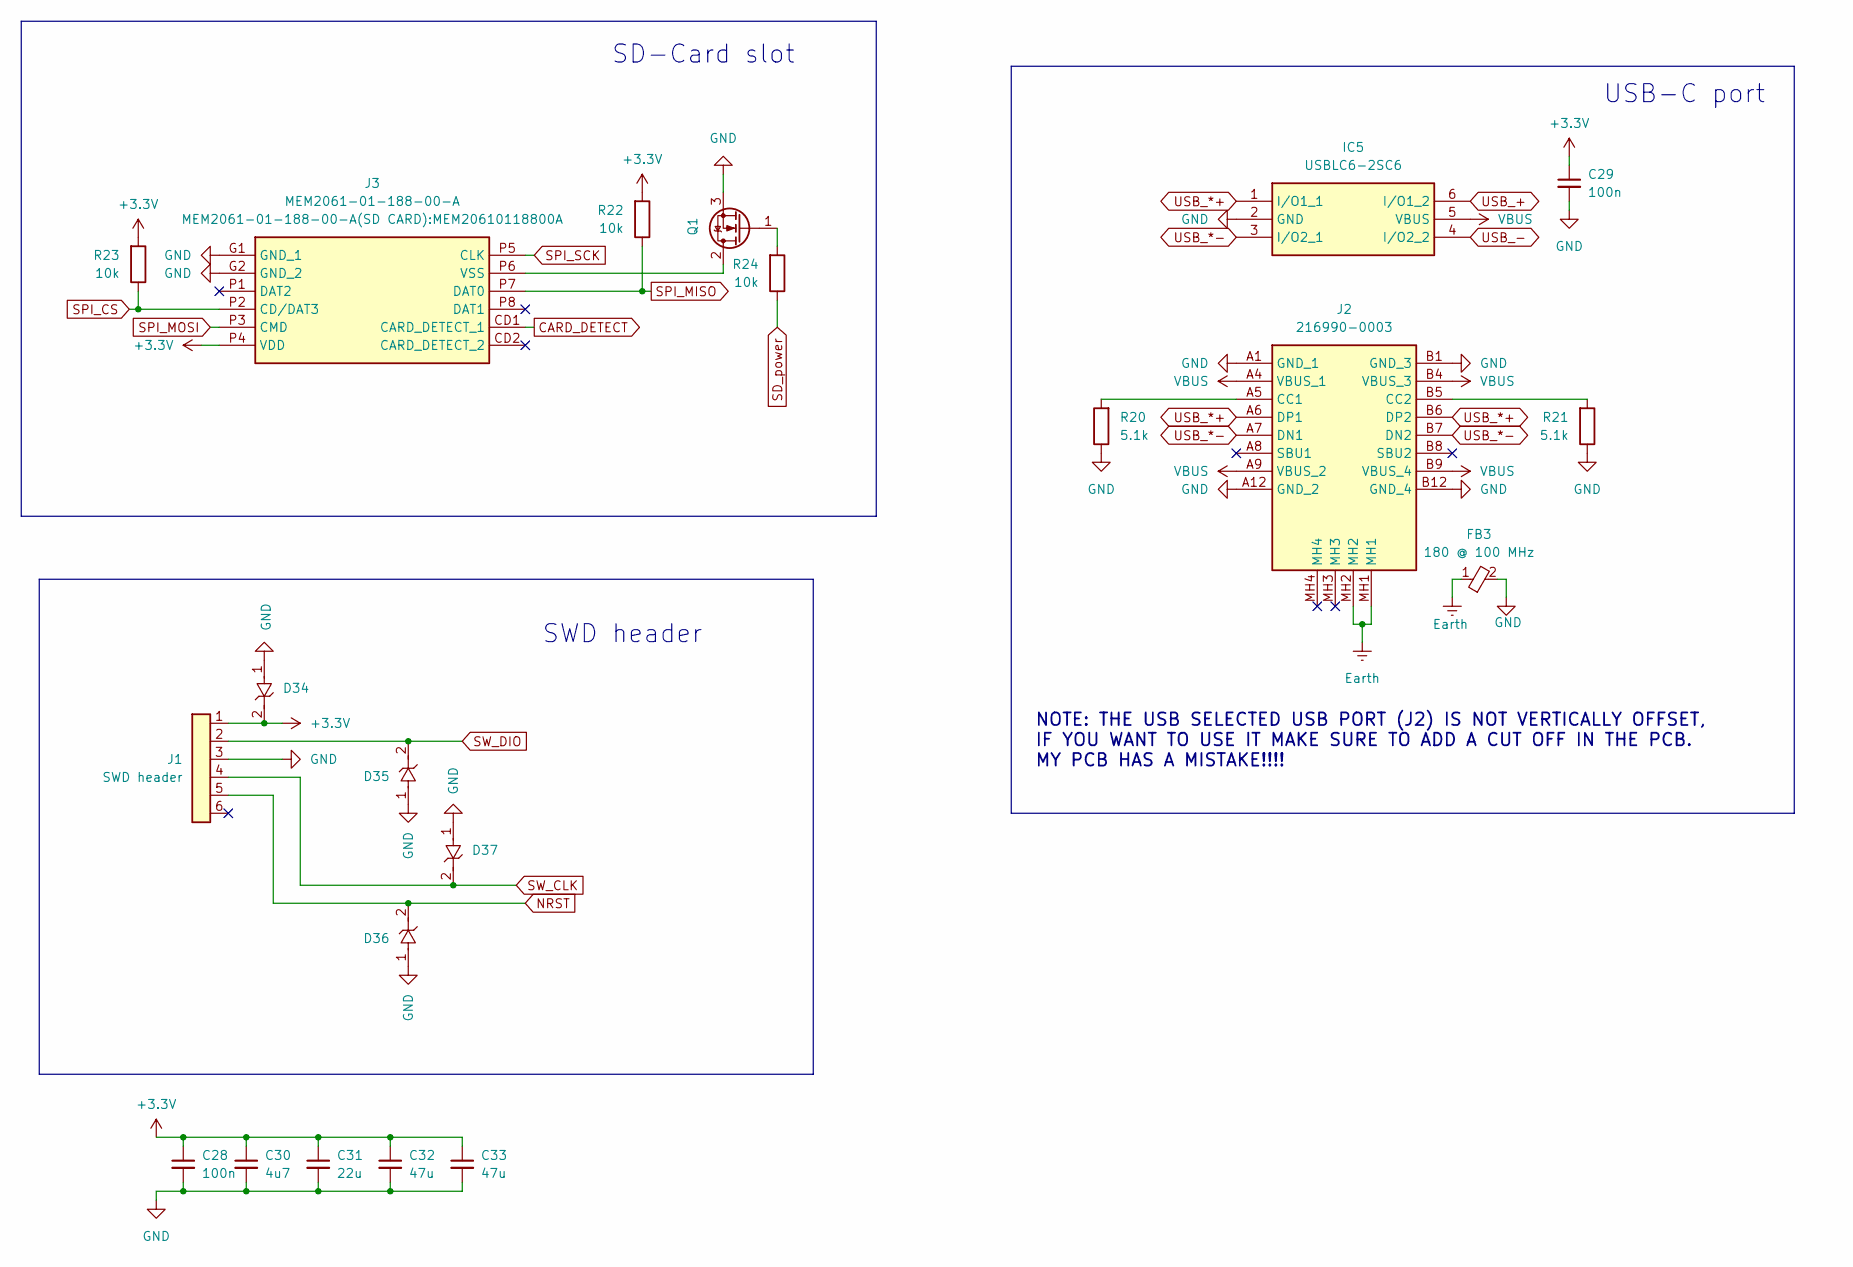
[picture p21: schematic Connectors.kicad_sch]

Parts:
C28, C29: 100n; C_0805_2012Metric_Pad1.18x1.45mm_HandSolder
C30: 4u7; C_0805_2012Metric_Pad1.18x1.45mm_HandSolder
C31: 22u; C_0805_2012Metric_Pad1.18x1.45mm_HandSolder
C32, C33: 47u; C_0805_2012Metric_Pad1.18x1.45mm_HandSolder
D34, D35, D36, D37: p4smaj65(DO-214AC)
FB3: 180 @ 100 MHz; ILBB0603ER181V
IC5: USBLC6-2SC6; SOT95P280X145-6N; Manufacturer_Part_Number USBLC6-2SC6; Mouser Part Number 511-USBLC6-2SC6
J1: SWD header; TSW-106-XX-YY-S; Manufacturer_Part_Number TSW-106-07-T-S; Mouser Part Number 200-TSW10607TS
J2: 216990-0003; Manufacturer_Part_Number 216990-0003; Mouser Part Number 538-216990-0003
J3: MEM2061-01-188-00-A; MEM20610118800A; Manufacturer_Part_Number MEM2061-01-188-00-A; Mouser Part Number 640-MEM20610118800A
Q1: BSS316NH6327XTSA1; SOT-23_Handsoldering
R20, R21: 5.1k; R_0603_1608Metric_Pad0.98x0.95mm_HandSolder
R22, R23, R24: 10k; R_0603_1608Metric_Pad0.98x0.95mm_HandSolder

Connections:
CARD_DETECT: J3.CD1 (CARD_DETECT_1); also elsewhere on the board
Earth: FB3.1, J2.MH1, J2.MH2
NRST: D36.2, J1.5; also elsewhere on the board
unnamed: J2.A5 (CC1), R20.2
unnamed: J2.B5 (CC2), R21.2
unnamed: J3.P6 (VSS), Q1.2 (D)
unnamed: Q1.1 (G), R24.2
SD_power: R24.1; also elsewhere on the board
SPI_CS: J3.P2 (CD/DAT3), R23.1; also elsewhere on the board
SPI_MISO: J3.P7 (DAT0), R22.1; also elsewhere on the board
SPI_MOSI: J3.P3 (CMD); also elsewhere on the board
SPI_SCK: J3.P5 (CLK); also elsewhere on the board
SW_CLK: D37.2, J1.4; also elsewhere on the board
SW_DIO: D35.2, J1.2; also elsewhere on the board
USB_*+: IC5.1 (I/O1_1), J2.A6 (DP1), J2.B6 (DP2)
USB_*-: IC5.3 (I/O2_1), J2.A7 (DN1), J2.B7 (DN2)
USB_+: IC5.6 (I/O1_2); also elsewhere on the board
USB_-: IC5.4 (I/O2_2); also elsewhere on the board
VBUS: IC5.5 (VBUS), J2.A4 (VBUS_1), J2.A9 (VBUS_2), J2.B4 (VBUS_3), J2.B9 (VBUS_4); also elsewhere on the board

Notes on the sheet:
USB-C port
NOTE: THE USB SELECTED USB PORT (J2) IS NOT VERTICALLY OFFSET, IF YOU WANT TO USE IT MAKE SURE TO ADD A CUT OFF IN THE PCB. MY PCB HAS A MISTAKE!!!!
SWD header
SD-Card slot

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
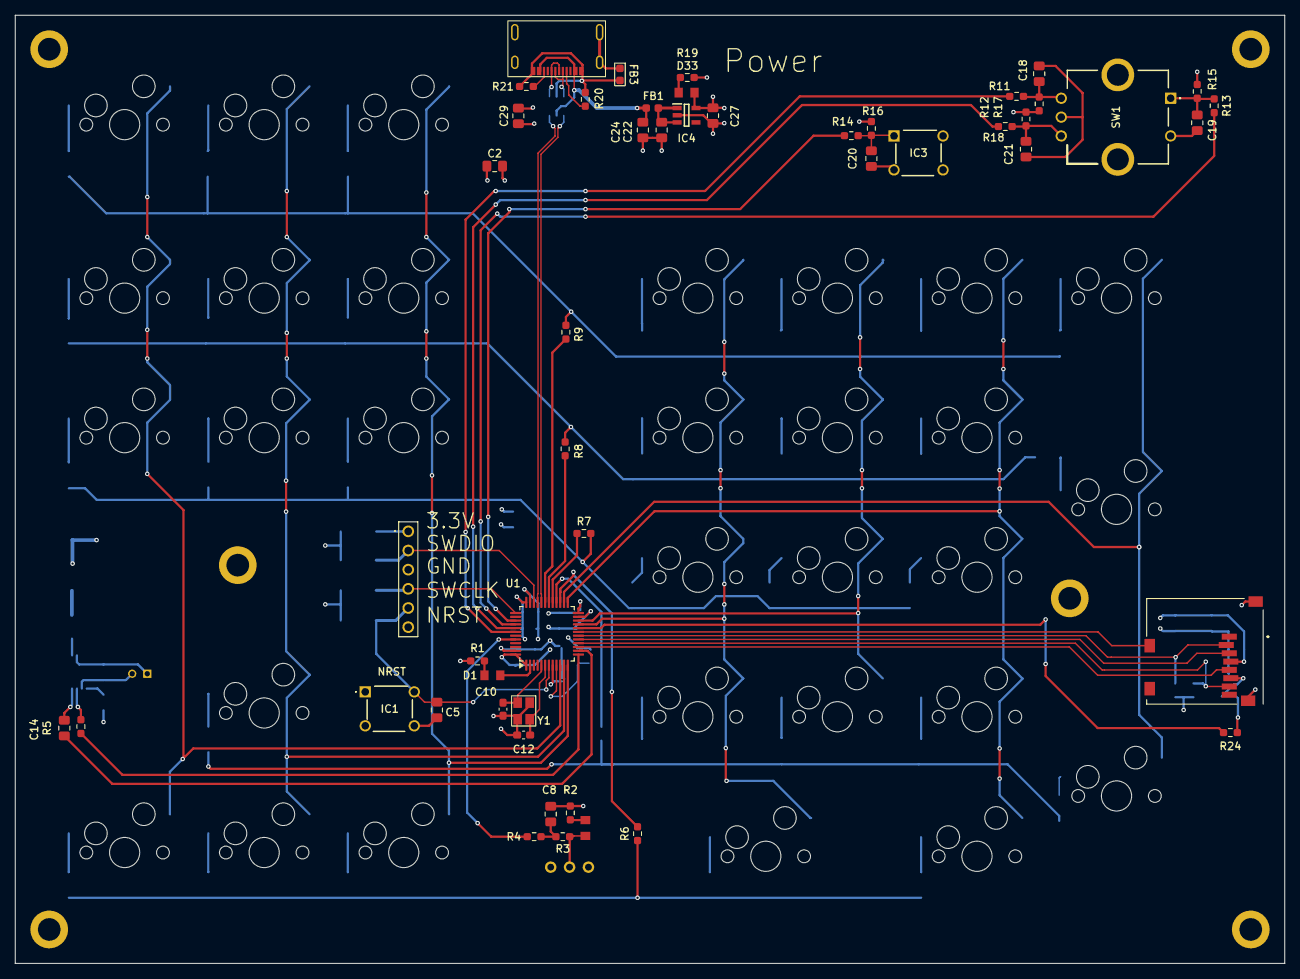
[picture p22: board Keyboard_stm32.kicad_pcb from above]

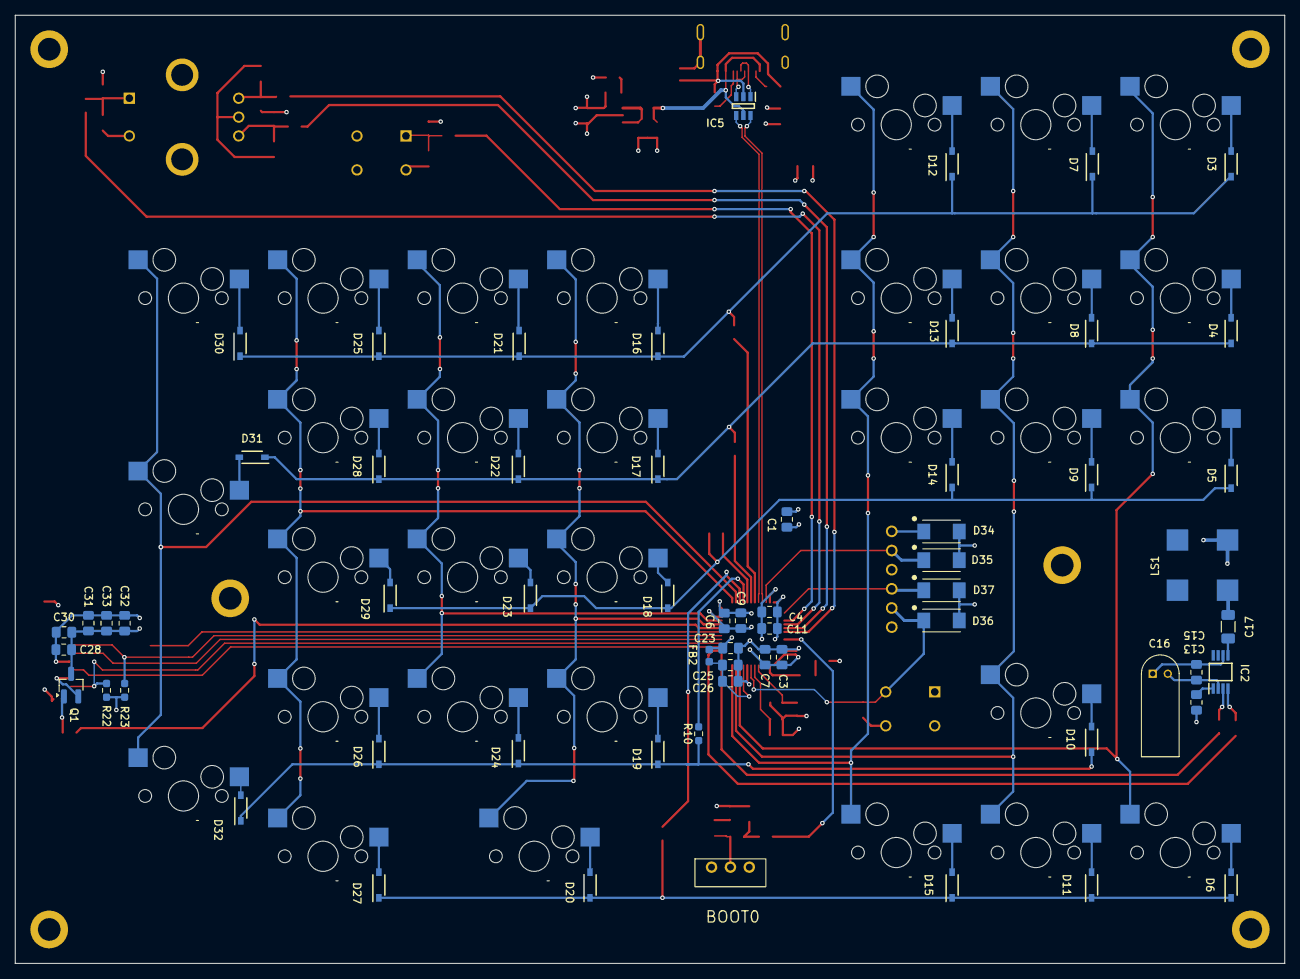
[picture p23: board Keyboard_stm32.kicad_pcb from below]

Board: 4 copper layers, 168.3 x 125.7 mm, 141 parts (61 on the bottom side), 96 nets.

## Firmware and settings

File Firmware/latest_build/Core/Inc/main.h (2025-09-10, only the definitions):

#define LED_STAT_Pin GPIO_PIN_13
#define LED_STAT_GPIO_Port GPIOC
#define CLM_1_Pin GPIO_PIN_0
#define CLM_1_GPIO_Port GPIOA
#define CLM_2_Pin GPIO_PIN_1
#define CLM_2_GPIO_Port GPIOA
#define CLM_3_Pin GPIO_PIN_2
#define CLM_3_GPIO_Port GPIOA
#define AMP_SHUTDWN_Pin GPIO_PIN_3
#define AMP_SHUTDWN_GPIO_Port GPIOA
#define SPI_CS_Pin GPIO_PIN_0
#define SPI_CS_GPIO_Port GPIOB
#define CARD_detect_Pin GPIO_PIN_1
#define CARD_detect_GPIO_Port GPIOB
#define CARD_SHUTDOWN_Pin GPIO_PIN_2
#define CARD_SHUTDOWN_GPIO_Port GPIOB
#define CLM_4_Pin GPIO_PIN_10
#define CLM_4_GPIO_Port GPIOB
#define CLM_5_Pin GPIO_PIN_11
#define CLM_5_GPIO_Port GPIOB
#define CLM_6_Pin GPIO_PIN_12
#define CLM_6_GPIO_Port GPIOB
#define CLM_7_Pin GPIO_PIN_13
#define CLM_7_GPIO_Port GPIOB
#define ROW_5_Pin GPIO_PIN_14
#define ROW_5_GPIO_Port GPIOB
#define ROW_4_Pin GPIO_PIN_15
#define ROW_4_GPIO_Port GPIOB
#define ROW_3_Pin GPIO_PIN_8
#define ROW_3_GPIO_Port GPIOA
#define ROW_2_Pin GPIO_PIN_9
#define ROW_2_GPIO_Port GPIOA
#define ROW_1_Pin GPIO_PIN_10
#define ROW_1_GPIO_Port GPIOA
#define PLAY_PAUSE_Pin GPIO_PIN_3
#define PLAY_PAUSE_GPIO_Port GPIOB
#define MUTE_Pin GPIO_PIN_4
#define MUTE_GPIO_Port GPIOB
#define ENC_B_Pin GPIO_PIN_5
#define ENC_B_GPIO_Port GPIOB
#define ENC_A_Pin GPIO_PIN_6
#define ENC_A_GPIO_Port GPIOB
#define DAC_FX_OUT DAC_CHANNEL_1
#define SYS_CLK_MHZ 48000U
#define DEFAULT_PRESCALER 119U
#define POWER_ON_SDCARD HAL_GPIO_WritePin(GPIOB, CARD_SHUTDOWN_Pin, GPIO_PIN_SET);
#define POWER_OFF_SDCARD HAL_GPIO_WritePin(GPIOB, CARD_SHUTDOWN_Pin, GPIO_PIN_RESET);
#define POWER_ON_AUDIO_AMP HAL_GPIO_WritePin(GPIOA, AMP_SHUTDWN_Pin, GPIO_PIN_SET);
#define POWER_OFF_AUDIO_AMP HAL_GPIO_WritePin(GPIOA, AMP_SHUTDWN_Pin, GPIO_PIN_RESET);
#define KEYBOARD_SCAN 1U
#define SEND_HID_REPORTS 2U
#define __LOGGING_ENABLED 0
#define __DEBUG 0
#define __AUDIO_FX_ENABLED 1

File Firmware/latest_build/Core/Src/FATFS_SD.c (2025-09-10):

/*
 * File: FATFS_SD.c
 * Driver Name: [[ FATFS_SD SPI ]]
 * SW Layer:   MIDWARE
 * Author:     Khaled Magdy
 * -------------------------------------------
 * For More Information, Tutorials, etc.
 * Visit Website: www.DeepBlueMbedded.com
 */
#include "main.h"
#include "diskio.h"
#include "FATFS_SD.h"

#define TRUE  1
#define FALSE 0
#define bool BYTE

static volatile DSTATUS Stat = STA_NOINIT;  /* Disk Status */
uint16_t Timer1, Timer2; 		/* 1ms Timer Counters */
static uint8_t CardType; 		/* Type 0:MMC, 1:SDC, 2:Block addressing */
static uint8_t PowerFlag = 0;	/* Power flag */

//-----[ SPI Functions ]-----

/* slave select */
static void SELECT(void)
{
  HAL_GPIO_WritePin(SD_CS_PORT, SD_CS_PIN, GPIO_PIN_RESET);
}

/* slave deselect */
static void DESELECT(void)
{
  HAL_GPIO_WritePin(SD_CS_PORT, SD_CS_PIN, GPIO_PIN_SET);
}

/* SPI transmit a byte */
static void SPI_TxByte(uint8_t data)
{
  while(!__HAL_SPI_GET_FLAG(HSPI_SDCARD, SPI_FLAG_TXE));
  HAL_SPI_Transmit(HSPI_SDCARD, &data, 1, SPI_TIMEOUT);
}

/* SPI transmit buffer */
static void SPI_TxBuffer(uint8_t *buffer, uint16_t len)
{
  while(!__HAL_SPI_GET_FLAG(HSPI_SDCARD, SPI_FLAG_TXE));
  HAL_SPI_Transmit(HSPI_SDCARD, buffer, len, SPI_TIMEOUT);
}

/* SPI receive a byte */
static uint8_t SPI_RxByte(void)
{
  uint8_t dummy, data;
  dummy = 0xFF;
  while(!__HAL_SPI_GET_FLAG(HSPI_SDCARD, SPI_FLAG_TXE));
  HAL_SPI_TransmitReceive(HSPI_SDCARD, &dummy, &data, 1, SPI_TIMEOUT);
  return data;
}

/* SPI receive a byte via pointer */
static void SPI_RxBytePtr(uint8_t *buff)
{
  *buff = SPI_RxByte();
}

//-----[ SD Card Functions ]-----

/* wait SD ready */
static uint8_t SD_ReadyWait(void)
{
  uint8_t res;
  /* timeout 500ms */
  Timer2 = 500;
  /* if SD goes ready, receives 0xFF */
  do {
    res = SPI_RxByte();
  } while ((res != 0xFF) && Timer2);
  return res;
}

/* power on */
static void SD_PowerOn(void)
{
  uint8_t args[6];
  uint32_t cnt = 0x1FFF;
  /* transmit bytes to wake up */
  DESELECT();
  for(int i = 0; i < 10; i++)
  {
    SPI_TxByte(0xFF);
  }
  /* slave select */
  SELECT();
  /* make idle state */
  args[0] = CMD0;   /* CMD0:GO_IDLE_STATE */
  args[1] = 0;
  args[2] = 0;
  args[3] = 0;
  args[4] = 0;
  args[5] = 0x95;
  SPI_TxBuffer(args, sizeof(args));
  /* wait response */
  while ((SPI_RxByte() != 0x01) && cnt)
  {
    cnt--;
  }
  DESELECT();
  SPI_TxByte(0XFF);
  PowerFlag = 1;
}

/* power off */
static void SD_PowerOff(void)
{
  PowerFlag = 0;
}

/* check power flag */
static uint8_t SD_CheckPower(void)
{
  return PowerFlag;
}

/* receive data block */
static bool SD_RxDataBlock(BYTE *buff, UINT len)
{
  uint8_t token;
  //since buff is zero indexed, len must be 512-1=511
  len--;
  /* timeout 200ms */
  Timer1 = 200;
  /* loop until receive a response or timeout */
  do {
    token = SPI_RxByte();
  } while((token == 0xFF) && Timer1);
  /* invalid response */
  if(token != 0xFE) return FALSE;
  /* receive data */
  do {  
    SPI_RxBytePtr(buff++);
  } while(len--);
  /* discard CRC */
  SPI_RxByte();
  SPI_RxByte();
  return TRUE;
}

/* transmit data block */
#if _USE_WRITE == 1
static bool SD_TxDataBlock(const uint8_t *buff, BYTE token)
{
  uint8_t resp;
  uint8_t i = 0;
  /* wait SD ready */
  if (SD_ReadyWait() != 0xFF) return FALSE;
  /* transmit token */
  SPI_TxByte(token);
  /* if it's not STOP token, transmit data */
  if (token != 0xFD)
  {
    SPI_TxBuffer((uint8_t*)buff, 512);
    /* discard CRC */
    SPI_RxByte();
    SPI_RxByte();
    /* receive response */
    while (i <= 64)
    {
      resp = SPI_RxByte();
      /* transmit 0x05 accepted */
      if ((resp & 0x1F) == 0x05) break;
      i++;
    }
    /* recv buffer clear */
    while (SPI_RxByte() == 0);
  }
  /* transmit 0x05 accepted */
  if ((resp & 0x1F) == 0x05) return TRUE;

  return FALSE;
}
#endif /* _USE_WRITE */

/* transmit command */
static BYTE SD_SendCmd(BYTE cmd, uint32_t arg)
{
  uint8_t crc, res;
  /* wait SD ready */
  if (SD_ReadyWait() != 0xFF) return 0xFF;
  /* transmit command */
  SPI_TxByte(cmd);          /* Command */
  SPI_TxByte((uint8_t)(arg >> 24));   /* Argument[31..24] */
  SPI_TxByte((uint8_t)(arg >> 16));   /* Argument[23..16] */
  SPI_TxByte((uint8_t)(arg >> 8));  /* Argument[15..8] */
  SPI_TxByte((uint8_t)arg);       /* Argument[7..0] */
  /* prepare CRC */
  if(cmd == CMD0) crc = 0x95; /* CRC for CMD0(0) */
  else if(cmd == CMD8) crc = 0x87;  /* CRC for CMD8(0x1AA) */
  else crc = 1;
  /* transmit CRC */
  SPI_TxByte(crc);
  /* Skip a stuff byte when STOP_TRANSMISSION */
  if (cmd == CMD12) SPI_RxByte();
  /* receive response */
  uint8_t n = 10;
  do {
    res = SPI_RxByte();
  } while ((res & 0x80) && --n);

  return res;
}

//-----[ user_diskio.c Functions ]-----

/* initialize SD */
DSTATUS SD_disk_initialize(BYTE drv)
{
  uint8_t n, type, ocr[4];
  /* single drive, drv should be 0 */
  if(drv) return STA_NOINIT;
  /* no disk */
  if(Stat & STA_NODISK) return Stat;
  /* power on */
  SD_PowerOn();
  /* slave select */
  SELECT();
  /* check disk type */
  type = 0;
  /* send GO_IDLE_STATE command */
  if (SD_SendCmd(CMD0, 0) == 1)
  {
    /* timeout 1 sec */
    Timer1 = 1000;
    /* SDC V2+ accept CMD8 command, http://elm-chan.org/docs/mmc/mmc_e.html */
    if (SD_SendCmd(CMD8, 0x1AA) == 1)
    {
      /* operation condition register */
      for (n = 0; n < 4; n++)
      {
        ocr[n] = SPI_RxByte();
      }
      /* voltage range 2.7-3.6V */
      if (ocr[2] == 0x01 && ocr[3] == 0xAA)
      {
        /* ACMD41 with HCS bit */
        do {
          if (SD_SendCmd(CMD55, 0) <= 1 && SD_SendCmd(CMD41, 1UL << 30) == 0) break;
        } while (Timer1);

        /* READ_OCR */
        if (Timer1 && SD_SendCmd(CMD58, 0) == 0)
        {
          /* Check CCS bit */
          for (n = 0; n < 4; n++)
          {
            ocr[n] = SPI_RxByte();
          }

          /* SDv2 (HC or SC) */
          type = (ocr[0] & 0x40) ? CT_SD2 | CT_BLOCK : CT_SD2;
        }
      }
    }
    else
    {
      /* SDC V1 or MMC */
      type = (SD_SendCmd(CMD55, 0) <= 1 && SD_SendCmd(CMD41, 0) <= 1) ? CT_SD1 : CT_MMC;
      do
      {
        if (type == CT_SD1)
        {
          if (SD_SendCmd(CMD55, 0) <= 1 && SD_SendCmd(CMD41, 0) == 0) break; /* ACMD41 */
        }
        else
        {
          if (SD_SendCmd(CMD1, 0) == 0) break; /* CMD1 */
        }
      } while (Timer1);
      /* SET_BLOCKLEN */
      if (!Timer1 || SD_SendCmd(CMD16, 512) != 0) type = 0;
    }
  }
  CardType = type;
  /* Idle */
  DESELECT();
  SPI_RxByte();
  /* Clear STA_NOINIT */
  if (type)
  {
    Stat &= ~STA_NOINIT;
  }
  else
  {
    /* Initialization failed */
    SD_PowerOff();
  }
  return Stat;
}

/* return disk status */
DSTATUS SD_disk_status(BYTE drv)
{
  if (drv) return STA_NOINIT;
  return Stat;
}
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

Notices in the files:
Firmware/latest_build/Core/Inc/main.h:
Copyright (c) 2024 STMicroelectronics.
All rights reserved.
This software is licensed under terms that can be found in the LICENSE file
